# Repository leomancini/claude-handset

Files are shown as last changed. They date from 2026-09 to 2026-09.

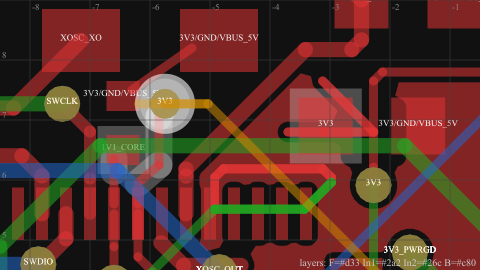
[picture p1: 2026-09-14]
patch-renders/caps_north_after_all.png

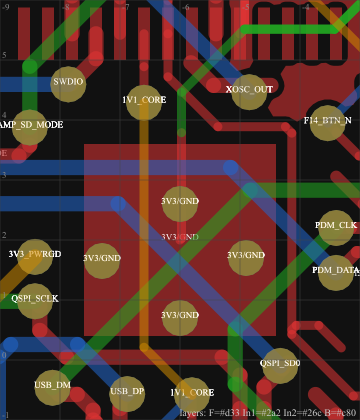
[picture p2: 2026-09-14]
patch-renders/site_ep.png

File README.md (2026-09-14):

# Claude Handset

60 mm round USB-C handset board: RP2040, MAX98357A speaker amp, Knowles PDM microphone, two
side buttons that send F13/F14 as a boot-compatible HID keyboard, all in one USB composite device.

Designed in [Flux](https://www.flux.ai/leomancini/claude-handset~2m). This repo holds the
hand-patched manufacturing files that were sent to JLCPCB (order 10211669A, September 2026),
the verification tooling, the enclosure STLs, and the ordering notes.

**Start with [CLAUDE.md](CLAUDE.md)** for the full hardware description, pin map, and firmware plan.

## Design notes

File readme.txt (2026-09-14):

Project Name: Claude Handset
Project Version: #3cf75256
Project Url: https://www.flux.ai/leomancini/claude-handset~2m

Project Description:
60 mm circular USB-C composite Audio + boot-compatible HID board with an onboard Knowles SPH0641LU4H-1 PDM MEMS microphone, MAX98357A amplified differential output for an 8 Ω speaker, and two separated diagonal side-actuated F13/F14 buttons.

Index:

Bottom Copper (Gerber): claude-handset-b_cu.gbr
Bottom Solder Mask (Gerber): claude-handset-b_mask.gbr
Bottom Solder Paste (Gerber): claude-handset-b_paste.gbr
Bottom Silkscreen (Gerber): claude-handset-b_silks.gbr
Board Outline (Gerber): claude-handset-edge_cuts.gbr
Top Copper (Gerber): claude-handset-f_cu.gbr
Top Solder Mask (Gerber): claude-handset-f_mask.gbr
Top Solder Paste (Gerber): claude-handset-f_paste.gbr
Top Silkscreen (Gerber): claude-handset-f_silks.gbr
Mid-Layer 1 (Gerber): claude-handset-in1_cu.gbr
Mid-Layer 2 (Gerber): claude-handset-in2_cu.gbr
Drill Holes (Excellon): claude-handset.drl
Electrical Test Netlist (IPC-D-356): claude-handset.d356
Component Positions, for assembly (Pick and Place, CSV): pick_and_place.csv

Bill of Materials: multiple versions are provided optimized for various contract manufacturers:

Bill of Materials (AdvancedCircuits): BOM/leomancini-claude-handset-BOM-V3cf75256-AdvancedCircuits.csv
Bill of Materials (AllPCB): BOM/leomancini-claude-handset-BOM-V3cf75256-AllPCB.csv
Bill of Materials (Elecrow): BOM/leomancini-claude-handset-BOM-V3cf75256-Elecrow.csv
Bill of Materials (Eurocircuits): BOM/leomancini-claude-handset-BOM-V3cf75256-Eurocircuits.csv
Bill of Materials (Flux): BOM/leomancini-claude-handset-BOM-V3cf75256-Flux.csv
Bill of Materials (JLCPCB): BOM/leomancini-claude-handset-BOM-V3cf75256-JLCPCB.csv
Bill of Materials (PCBWay): BOM/leomancini-claude-handset-BOM-V3cf75256-PCBWay.csv
Bill of Materials (Seeed): BOM/leomancini-claude-handset-BOM-V3cf75256-Seeed.csv

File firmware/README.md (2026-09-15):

# Claude Handset firmware

RP2040 firmware for the handset PCB. One USB full-speed composite device:

| Interface | What it is |
|---|---|
| UAC2 audio, speaker | 48 kHz, 16-bit stereo OUT, asynchronous with an explicit feedback endpoint. Mixed to mono, host volume + mute applied in firmware, played through the MAX98357A over I2S. The amp's SD_MODE pin is only high while the host is streaming and not muted. |
| UAC2 audio, microphone | 48 kHz, 16-bit mono IN. The Knowles PDM mic is clocked at 3.072 MHz by PIO and decimated in firmware (sinc⁴ ÷32 → DC blocker → half-band FIR ÷2). Host "input volume" is a digital gain, 0 to +30 dB, default +12 dB. |
| HID keyboard | Boot-protocol keyboard. SW1 sends **F17**, SW2 sends **F18** (see *Keys* below). 10 ms debounce, remote wakeup. |
| Reset | Raspberry Pi vendor "reset" interface so `picotool` can reboot the board into BOOTSEL without touching the buttons. |

macOS enumerates it as "Claude Handset" with 2 output and 1 input channel; the buttons show up as a keyboard.

## Build

Needs cmake, ninja, an `arm-none-eabi` GCC and the Pico SDK 2.3.1 (with its TinyUSB submodule). `build.sh` looks for the SDK in `~/.pico-sdk/sdk/2.3.1` and the toolchain in `~/.pico-sdk/toolchain/*/bin`, or set `PICO_SDK_PATH` / `PICO_TOOLCHAIN_PATH`.

```sh
brew install cmake ninja picotool
mkdir -p ~/.pico-sdk/sdk && git clone --depth 1 --branch 2.3.1 https://github.com/raspberrypi/pico-sdk ~/.pico-sdk/sdk/2.3.1
git -C ~/.pico-sdk/sdk/2.3.1 submodule update --init --depth 1 lib/tinyusb
# ARM toolchain: unpack arm-gnu-toolchain-*-darwin-arm64-arm-none-eabi.tar.xz into ~/.pico-sdk/toolchain/

./build.sh                        # -> build/claude_handset/claude_handset.uf2
./build.sh claude_handset_kb2040  # bench build for an Adafruit KB2040 wired to the same GPIOs
```

## Flash

```sh
./flash.sh          # picotool load -f --vid 0x1209 --pid 0x0001 -x build/claude_handset/claude_handset.uf2
```

Works in three states: blank flash (board boots straight into the ROM bootloader), a board put into BOOTSEL by hand (hold SW4, tap SW3, release SW4), or this firmware running (the reset interface reboots it). picotool only looks for the reset interface on Raspberry Pi's VID unless `--vid/--pid` are given, hence the flags.

## Recovery and crash diagnostics

The main loop feeds a 2 s watchdog. If it ever stalls:

1. First watchdog reboot: the board comes back normally but its USB serial number gets a suffix, `<uid>-WDT<stage>-<pc>-<loops>` (hex). `stage` is the last breadcrumb (`DIAG_CRUMB` in the sources; 10–15 = main-loop tasks, 20–24 speaker path, 3x set-interface, 4x control requests). Bit 0x8000 set = hard fault and `pc` is the faulting address; bit 0x4000 = `panic()` and `pc` is the address of the format string, `loops` the caller. Map addresses with `arm-none-eabi-addr2line -e build/claude_handset/claude_handset.elf`.
2. Second watchdog reboot in a row (within 10 s of boot): the board drops into the ROM bootloader and shows up as RPI-RP2, so it can always be reflashed.

Read the serial with `ioreg -p IOUSB -l -w0 | grep kUSBSerialNumberString`.

## Keys

The board was designed around F13/F14, but macOS binds F14/F15 to display brightness on keyboards without dedicated keys, so the firmware sends F17 and F18, which have no default binding on macOS, Windows or Linux. Change `HANDSET_KEY_SW1` / `HANDSET_KEY_SW2` in `src/buttons.c` to move them. `tools/keytest.html` is a browser page that lights up when the keys arrive.

## Live status

`tools/handset-status.c` reads a status block (stream state, amp pin, power-good, FIFO levels, frame counters, PIO/DMA positions) from the running board over the reset interface. Needs `brew install libusb`:

```sh
cc -O -o handset-status tools/handset-status.c -I/opt/homebrew/include -L/opt/homebrew/lib -lusb-1.0
./handset-status        # once
./handset-status 1      # every second
```

## Tunables

All in `src/usb_audio.c`:

- `SPK_HEADROOM_DB` (−6 dB): fixed attenuation on top of the host volume. The amp has 9 dB of gain and the board must stay under the 500 mA fuse, so a full-scale signal is never sent. Raise with a current meter in hand.
- `SPK_VOL_*_DB`, `MIC_VOL_*_DB`: ranges and defaults advertised to the host.
- `SPK_I2S_TARGET_FRAMES` (192 = 4 ms): how far ahead of the DMA reader the I2S ring is kept. Total speaker latency is this plus ~4 ms of USB FIFO.

`-DPDM_SAMPLE_ON_HIGH_PHASE=1` selects the alternate PDM sample edge (see `src/pdm_mic.pio`).

## Layout

```
boards/           board headers (claude_handset.h: pin map, 2 MB flash, QSPI /4)
src/main.c        init order + cooperative main loop
src/usb_descriptors.[ch]  device/config/string descriptors, UAC2 topology, HID report
src/usb_audio.[ch]        UAC2 requests, stream on/off, speaker + mic tasks, amp enable,
                          RP2040 ISO endpoint workaround
src/i2s_out.[ch] + .pio   I2S TX: PIO + two chained DMA channels on a 4 KB ring
src/pdm_mic.[ch] + .pio   PDM RX: PIO + DMA ring, CIC/half-band decimator
src/buttons.[ch]          debounce + HID keyboard reports
src/usb_reset.c           picotool reset interface + status request (TinyUSB app class driver)
src/handset_status.h      status block layout shared with tools/handset-status.c
src/diag.[ch]             watchdog policy, breadcrumbs, panic/hard-fault capture
src/tusb_config.h         TinyUSB configuration
tools/keytest.html        browser key tester
tools/handset-status.c    libusb tool that dumps the live status block
```

## Notes on things that bit

- **TinyUSB RP2040 ISO endpoints**: `usbd_edpt_close()` is a no-op on this port and re-activating an ISO endpoint does not clear its hardware buffer control. When the host stops a stream while a buffer is armed and later restarts it, the driver panics with "ep was already available". `rp2040_abort_endpoint()` in `usb_audio.c` aborts and clears the endpoints whenever a streaming interface goes to alt 0.
- **Feedback endpoint format**: on full speed the host expects a 3-byte 10.14 rate value. With TinyUSB's `CFG_TUD_AUDIO_ENABLE_FEEDBACK_FORMAT_CORRECTION` off it sends 4-byte 16.16, which macOS rejects: it delivers ~64 ms of audio, then stops sending packets for good while the interface stays at alt 1. Keep the correction on.
- **PDM sample point**: sample the data line on the clock edge that ends the mic's driving phase, with the PIO input synchroniser bypassed. Sampling near the other edge lands in the mic's output transition and shows up as noise.
- **DC blocker**: a first-order integer DC blocker leaves a residual of up to 255 counts unless the leak term keeps fractional bits; it is accumulated in Q8.
- **macOS makes a new USB audio device the default input and output.** Handy for testing, surprising for system sounds. `SwitchAudioSource` or the Sound settings put it back.

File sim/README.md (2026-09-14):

# Wiring simulator

Pure-Python (no dependencies) simulator that tests the board *as built from the copper*, not as
drawn in the schematic.

```
python3 sim/extract_netlist.py     # copper -> asbuilt_netlist.json  (about 2 min)
python3 sim/simulator.py           # DC simulation + wiring tests   -> results.md
```

## What it does

1. **extract_netlist.py** parses the four copper Gerbers and the drill file, unions every trace,
   pad, via and fill that physically touches (honouring negative-polarity clears), and drops every
   IPC-D-356 netlist point onto the resulting copper islands. Each island becomes one as-built net.
   Orphan pads, shorted nets and split nets are reported.

2. **simulator.py** builds a DC circuit on those as-built nets:
   - resistor values from `pick_and_place.csv`; fuse, ferrite, ESD-array pass-through and the
     8 Ω speaker as small resistances; switches open/closed per scenario;
   - behavioural MCP1825 LDO (3.3 V, dropout, open-drain PWRGD), RP2040 core regulator, GPIO
     drivers and internal pull-ups, and the supply currents of every IC;
   - RP2040 pin numbers are recovered from pad geometry and cross-checked against the netlist
     labels, so tests can refer to GPIO numbers.

   It then runs:
   - **netlist equivalence**: copper vs intended nets, GPIO assignments from the project description;
   - **two-terminal wiring paths**: 51 resistance measurements through the passive network
     (USB D+/D- through the ESD array and 27 Ω, CC pull-downs, QSPI to the flash, I2S and
     SD_MODE to the amp, PDM to the mic, SWD header, crystal, speaker, pull-ups, switches, and
     "must be open" pairs such as 3V3-GND and D+ to D-);
   - **decoupling placement**: net membership and distance of the nearest capacitor to every
     supply pin (warnings only);
   - **DC scenarios**: USB idle, each button, reset, BOOTSEL, debugger RUN, amp playing at 1 W,
     amp off, USB brown-out (PWRGD must go low), USB unplugged. Node voltages, fuse current and
     LDO dissipation are checked against expected windows.

Run against a different export with `GERBER_ROOT=<dir> NETLIST_OUT=<file>` for the extractor and
`NETLIST_IN=<file> RESULTS_OUT=<file>` for the simulator. `results_original.md` is the same
suite run on the untouched Flux export, where it flags the short and the opens.

## Limits

DC only: capacitors and the crystal are open circuits, so oscillator start-up, USB signal
integrity and audio are not simulated. Load currents and the SD_MODE pull-down are datasheet
estimates (listed at the end of `results.md`).

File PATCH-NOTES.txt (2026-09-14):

Claude Handset  #3cf75256  -  hand-patched Gerber export
=========================================================
These Gerbers were edited directly (the Flux project was NOT changed) to fix the
DRC faults Flux reported. Coordinates below are mm from the board centre, the same
origin as the IPC-D-356 netlist. Original files are byte-identical to the Flux
export except for the items listed here.

1. 3V3 shorted to 3V3_PWRGD (Flux "Overlapping Copper", Through-hole - 1)
   - Removed the 3V3 via at (-1.50, 4.00). It sat on the PWRGD trace and also
     overlapped the second 3V3 via 0.35 mm away.
   - Kept the 3V3 via at (-1.42, 3.66); its pad is now 0.5 mm (0.3 mm drill) on
     all four layers so it clears the PWRGD trace by 0.16 mm.
   - Deleted the three 0.1 mm top-layer feeder segments to the removed via and
     added a 0.15 mm segment from the existing 3V3 trace end (-1.83, 3.41) to the
     kept via.

2. 3V3 open (Flux "Airwire" 3V3, traces 7d11 / dcde)
   - The group feeding RP2040 VREG_VIN, USB_VDD, ADC_AVDD and three IOVDD pins
     (with C7, C8, C9, C13, C15, C16) was isolated.
   - Added a 3V3 via at (-12.79, -8.20) on the existing 3V3 trace just below
     FB1 pin 1, and a 0.254 mm inner-layer-1 trace from it to the existing 3V3
     via at (-9.16, -5.86). The ground planes on In1, In2 and Bottom are cleared
     0.2 mm around the new via and trace (negative-polarity LPC objects at the end
     of each copper file); the top ground fill is cleared around the via too.
   - Deleted the redundant top-layer 3V3 trace (-4.29,-4.00)-(-6.09,-4.00)-
     (-6.24,-1.47) between C10 and C14 (both ends are fed elsewhere) to make room
     for item 3.

3. GND opens (Flux "Airwire" GND, C10:P2 / C14:P2, traces 549b / ee7e, and the
   "Fill: None" items)
   - RP2040 exposed pad had no ground connection at all: added four 0.6 mm GND
     vias inside it at (-7.30, 1.65), (-4.90, 1.70), (-6.00, 2.60), (-6.00, 0.70).
   - C10:P2 and C14:P2: added a GND via at (-5.80, -4.10) with 0.25 mm links into
     both pads.
   - C13:P2 / C16:P2: added a 0.5 mm-pad GND via at (-8.50, -6.40) with a 0.3 mm
     link from the end of their wide stub at (-8.23, -6.06).

4. Drill file and IPC-D-356 netlist updated to match (7 vias added, 1 removed,
   one via pad size changed). Solder mask / paste files untouched: all vias in
   this export are tented, and no via was placed inside an SMD pad.

Verification (script-based, pure geometry from the Gerbers + netlist):
   - every net is one copper island; no island carries two nets; no floating copper
   - no new copper-to-copper spacing below 0.127 mm was introduced; the deleted
     0.1 mm feeders removed the worst pre-existing spacing (0.044 mm)
   - JLCPCB 4-layer limits used: 0.09 mm spacing, 0.15 mm via hole, 0.25 mm via pad

Not fixed (pre-existing, outside the DRC list): several spacings under 0.09 mm
remain from the original layout, e.g. USB-C pads vs traces at 0.050 mm around
(-0.25, -21.3), MCU_RUN pad vs SWDIO trace 0.069 mm at (-7.8, 5.4), F13/F14 button
traces vs 3V3 near the RP2040 east pins 0.069-0.089 mm.

Renders of the edited areas are in patch-renders/ (orig_* = before, site_* = after;
red = top, green = In1, blue = In2, orange = bottom).

Patch 2 - decoupling capacitors moved next to the pins they serve
================================================================
   - C24 (100 nF, VBUS_5V) moved from (7.0, -0.5) to (12.3, -4.6), directly below the
     MAX98357A VDD pins; its VBUS pad sits on the existing VDD trace, its GND pad on the
     top ground fill. Old pads and the two feeder segments removed. 1.18 mm from the pin.
   - C11 (100 nF, 1V1_CORE) moved from (-0.5, -3.0) to (-6.45, 6.95) and changed to an 0402
     (Samsung CL05B104KO5NNNC, LCSC C1525) so it fits between the RP2040's north pin row and
     the crystal. Its 1V1 pad is fed straight up from pin 23 (DVDD); its GND pad links to the
     crystal's GND pad. 1.07 mm from the pin. The BOMs and pick-and-place carry the new
     footprint. Old pads and five feeder stubs removed.
   - C6 (100 nF, 3V3) moved from (-1.5, 6.8) to (-2.3, 6.9), the closest an 0603 can get to
     RP2040 pin 22 (north IOVDD) without rerouting the crystal: 3.45 mm instead of 4.15 mm.
     Its 3V3 pad picks up the existing 3V3 stubs, its GND pad sits on the ground fill.
   - To make room for C11, pin 22's 3V3 feed now leaves the pad diagonally to x = -5.85 and
     the 3V3 via that fed it moved from (-6.19, 7.27) to (-5.75, 7.27) with a 0.5 mm pad;
     the bottom-layer 3V3 trace was redrawn to end on the moved via.
   - Top ground fill cleared 0.15 mm around every relocated non-GND pad and along the new
     top traces (negative-polarity objects at the end of f_cu); plane clearances added on
     the inner/bottom layers for the moved via. Mask and paste openings follow the pads;
     silkscreen body marks moved with the parts (the C24 label moved, the C6 and C11 labels
     were left where they were).
   - Re-verified: no shorts, no opens, no new spacing below 0.127 mm; wiring simulator
     142/143 with the remaining note being C6 at 3.45 mm.
   Renders: patch-renders/caps_north_*.png and caps_amp_*.png. Files before patch 2 are in
   the session scratchpad only; original-flux-export/ still holds the untouched export.

Gerber syntax note (after patch 2)
----------------------------------
   The patch blocks had deleted all file attributes (%TD*%) before the export's own trailing
   %TD.AperFunction*%, which a strict RS-274X parser rejects as deleting an undefined attribute.
   A %TA.AperFunction,Conductor*% line was added before that trailer in the four copper files.
   All 12 files now parse cleanly with an independent parser (gerbonara 1.x); the negative-
   polarity clearances render as intended there too. jlcpcb/ holds the upload pack.

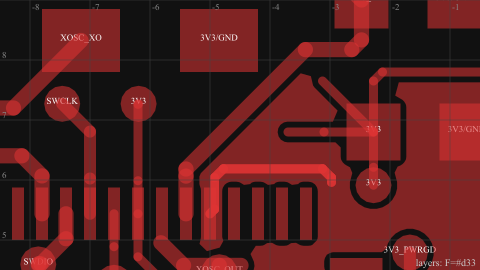
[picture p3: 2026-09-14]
patch-renders/caps_north_before.png

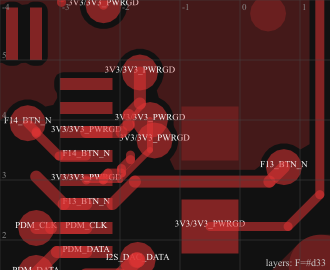
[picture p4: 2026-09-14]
patch-renders/orig_short_F.png

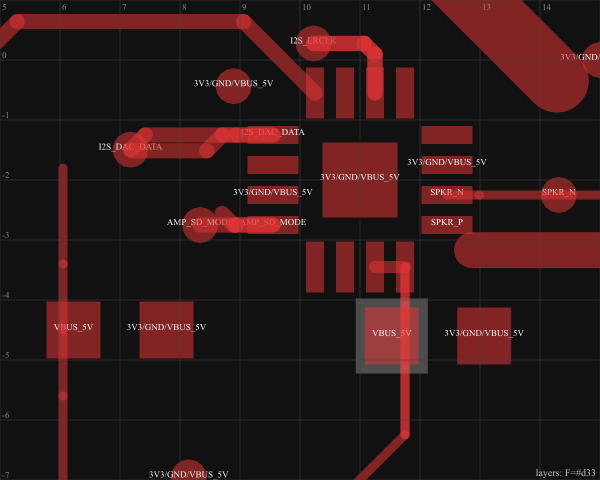
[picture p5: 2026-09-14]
patch-renders/caps_amp_after.png

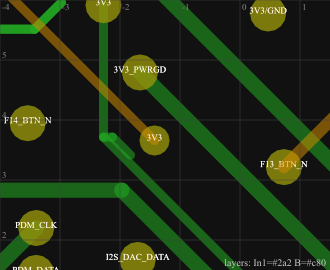
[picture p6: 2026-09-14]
patch-renders/site_short_In1B.png

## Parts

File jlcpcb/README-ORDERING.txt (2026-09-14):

Claude Handset  #3cf75256 (patched)  -  JLCPCB order pack
=========================================================

Files in this folder
--------------------
claude-handset-gerbers-v3cf75256-patched.zip   upload this in "Add gerber file"
                                              (11 Gerber layers + Excellon drill, RS-274X)
claude-handset-BOM-JLCPCB.csv                  BOM in JLCPCB's format (Comment, Designator, Footprint, LCSC Part #)
claude-handset-CPL-JLCPCB.csv                  component placement list (Designator, Mid X, Mid Y, Layer, Rotation)

PCB order settings (the quote form defaults are NOT right for this board)
------------------------------------------------------------------------
Base material ............ FR-4
Layers ................... 4          <- the form defaults to 2; this board has two inner planes
Dimensions ............... 60 x 60 mm (round board, the outline file sets the shape)
PCB thickness ............ 1.6 mm
Surface finish ........... ENIG recommended (0.4 mm pitch QFN-56 and USON-8 flash); HASL works for a prototype
Outer / inner copper ..... 1 oz / 0.5 oz
Via covering ............. Tented (all vias are tented in the export)
Min via hole / diameter .. 0.3 mm / 0.5 mm are the smallest used (JLC 4-layer min is 0.15 / 0.25)
Impedance control ........ No
Remove order number ...... "Specify a location" is not set up; choose "No" or "Yes" (JLC picks a spot)
Confirm production file .. Yes (recommended, see "things to check" below)

Assembly (if ordering SMT)
--------------------------
Side ...................... Top only (all 51 parts are on the top side)
Every part carries an LCSC number. JLCPCB's BOM matcher also finds U5 (MCP1825T-3302E/DC) as
C622691 even though the BOM cell is blank; if it ever shows unmatched, use C622691 or the
pin-compatible 1 A sibling MCP1826T-3302E/DC (C512184). Do NOT accept MCP1825S / MCP1825ST
(3-pin versions): they have no SHDN/PWRGD pins.
J1 (USB4105-GF-A, C3020560) is flagged "difficult to process" and JLCPCB leaves its row
UNSELECTED (qty 0) after the BOM upload. Click its magnifier, search C3020560, press Select;
it then shows qty 5 and adds a $0.03/pc special-component fee. In stock (1158 on 3 Sep 2026).
J3 (JST PH right-angle header) is through-hole: JLCPCB quotes it as hand-soldered, or leave it off
and solder it yourself. All other parts are SMD on the top side.
Rotation: JLCPCB re-orients parts to their library convention during review; check the pin-1
orientation of U1, U2, U3, U5, D1 in the assembly preview before confirming.

Things to check in JLCPCB's Gerber viewer / DFM before confirming
-----------------------------------------------------------------
1. This export was hand-patched (see ../PATCH-NOTES.txt). Copper clearances around the new
   parts use negative-polarity Gerber objects (%LPC). Both my own checker and an independent
   parser (gerbonara) read them correctly; still, look at these four spots in the viewer and
   make sure the 3V3 pads/vias are NOT merged into the ground fill:
     - the via just below FB1 at board-centre coords (-12.8, -8.2)
     - the RP2040's north side, (-7 .. -2, 6 .. 8): C6, C11 and the moved 3V3 via
     - below the amp U3 at (11.5, -4.6): C24
     - the 3V3 via at (-1.4, 3.7) next to the RP2040's east pins
2. The original Flux layout has several spacings below JLCPCB's 0.09 mm minimum that were not
   touched: USB-C pads vs traces at 0.05 mm around (-0.3, -21.3), RUN pad vs SWDIO trace 0.07 mm
   at (-7.8, 5.4), F13/F14 traces vs 3V3 near the RP2040 east pins at 0.07-0.09 mm. Expect an
   engineering query; accept their "adjust spacing" fix if offered.
3. Silkscreen: the labels "C6" and "C11" still sit at the parts' old positions (cosmetic).

Cart as saved on 3 September 2026 (order 10211669A, not paid)
--------------------------------------------------------------
PCB   : 4 layers, 1.6 mm, ENIG, plugged vias, Confirm Production File = Yes ........ $28.38
PCBA  : Standard, top side, 5 pcs, 26 parts, Confirm Parts Placement = Yes ......... $154.40
U3 (MAX98357A) was rotated right 90 deg in the placement viewer so its pin-1 dot sits on the
footprint's pin-1 mark (top-left). All other parts were accepted as auto-aligned.
Note: the cart lists the PCB dimension as 70 x 70 mm. The outline is a 60 mm circle whose
Gerber coordinates span 10..70 mm, and JLCPCB measured from the origin. Production follows
the outline file; the size only affects price. Correct it to 60 x 60 in "Edit Order" if you
want the exact quote (last time Edit Order removed the item and re-saving failed, so only
do it if you are prepared to rebuild the cart).

Engineer query 4 September 2026 (order 10211669A): C25 pads too small for the part
------------------------------------------------------------------------------------
Correct. Flux's BOM put C25 on the 0805 line (C15850) but the copper footprint is 0603
(same pads as C1). Answer: option A, replace C25 with C96446 (CL10A106MA8NRNC, 10uF 25V
X5R 0603), the same part as C1. The BOM and CPL in this folder are now corrected, so a
future upload will not repeat it. All other passives were checked against their pads: OK.
Resolution 5 September 2026: JLCPCB's Replace Parts page groups C2, C25, C3 on one line, so
the whole line was switched to C96446 (0603) for this order. C2 and C3 sit on 0805 pads with
the smaller body; electrically identical. The BOM here keeps C2/C3 on C15850 (0805) and C25
on C96446 (0603), which is the correct split for any future order.

Production-file check 5 September 2026 (JLCPCB pack ~/Downloads/claude-handset-gerbers-v3cf75256-patched_Y8)
-----------------------------------------------------------------------------------------------------------
Their CAM output (ok/tl, l2, l3, bl, ts, bs, to, drl, ko) was compared against the uploaded files
(shift is exactly -5 mm, +75 mm; YG/ zip is byte-identical to the upload).
  copper top/bottom ... identical inside the board outline
  copper inner ........ identical except non-functional via/through-hole pads removed (standard CAM step)
  copper at edges ..... pulled back ~0.3 mm from the board edge and from the NPTH mic hole (standard)
  solder mask ......... identical, plus mask opened over the USB-C NPTH slots and the mic hole
  silkscreen .......... identical, clipped where it crossed pads
  drill ............... all 114 holes and 4 USB-C slots present; 4 extra tooling holes in the rails
  connectivity ........ netlist replayed on THEIR copper: 319 pads, 0 opens, 0 shorts
  panel ............... 70 x 70 mm frame: 5 mm rails left/right, 3 mm top/bottom, QR code + tooling
                        holes on the rails, via plugging list (sk). This is why the order says 70 x 70.
                        Boards ship in the frame (depanel = No); snap them out. Expect small flats/rough
                        spots at the 3 and 9 o'clock edges where the tabs were.
Verdict: OK to confirm.

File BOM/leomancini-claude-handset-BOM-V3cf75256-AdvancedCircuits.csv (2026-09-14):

Component Description | QTY | Ref Des | Mfg P/N # | Manufacturer | Distributor P/N #
Non-Polarized Capacitor, 10uF, SMD_0603_1608Metric | 1 | C1 | CL10A106MA8NRNC | Samsung Electro-Mechanics | C96446
Non-Polarized Capacitor, 10uF, SMD_0805_2012Metric | 3 | C2,C25,C3 | CL21A106KAYNNNE | Samsung Electro-Mechanics | C15850
Non-Polarized Capacitor, 100nF, SMD_0603_1608Metric | 13 | C10,C15,C16,C17,C20,C24,C28,C4,C5,C6,C7,C8,C9 | CL10B104KB8NNNC | Samsung Electro-Mechanics | C1591
Non-Polarized Capacitor, 100nF, SMD_0402_1005Metric | 1 | C11 | CL05B104KO5NNNC | Samsung Electro-Mechanics | C1525
Non-Polarized Capacitor, 27pF, SMD_0603_1608Metric | 2 | C12,C18 | CL10C270JB8NNNC | Samsung Electro-Mechanics | C1656
Non-Polarized Capacitor, 1uF, SMD_0603_1608Metric | 2 | C13,C14 | CL10A105KB8NNNC | Samsung Electro-Mechanics | C15849
Non-Polarized Capacitor, 47pF, SMD_0603_1608Metric | 1 | C29 | CL10C470JB8NNNC | Samsung Electro-Mechanics | C1671
Protection | 1 | D1 | USBLC6-2SC6 | STMicroelectronics
TVS, SOD-123FL_L2.8-W1.8-LS3.6-RD | 1 | D2 | SMF5.0A | Liown(里阳半导体)
Circuit Protection Devices | 1 | F1 | SMD050F-2 | Littelfuse | C428837
Ferrite Bead | 1 | FB1 | BLM18AG601SN1D | Murata Electronics | C19330
USB C | 1 | J1 | USB4105-GF-A | GCT | C3020560
Wire To Board / Wire To Wire Connector, CONN-TH_S2B-PH-K-S-LF-SN | 1 | J3 | S2B-PH-K-S(LF)(SN) | JST
Connector | 1 | J4 | FTSH-103-01-L-DV | Samtec | C3324375
Microphone | 1 | MK1 | SPH0641LU4H-1 | Knowles | C2879853
Resistor, 5.1kΩ, SMD_0603_1608Metric | 2 | R1,R2 | 0603WAF5101T5E | UNI-ROYAL | C23186
Resistor, 27Ω, SMD_0603_1608Metric | 2 | R3,R4 | 0603WAF270JT5E | UNI-ROYAL | C25190
Resistor, 1kΩ, SMD_0603_1608Metric | 2 | R5,R6 | 0603WAF1001T5E | UNI-ROYAL | C21190
Resistor, 10kΩ, SMD_0603_1608Metric | 5 | R14,R15,R7,R8,R9 | 0603WAF1002T5E | UNI-ROYAL | C25804
Switch | 2 | SW1,SW2 | B3U-3000P | Omron Electronics Inc-EMC Div | C963349
Tactile Switches, SW-SMD_L3.9-W3.0-P4.45 | 2 | SW3,SW4 | TS-1088-AR02016 | XUNPU(讯普)
, QFN-56-1EP_7x7mm_P0.4mm_EP3.2x3.2mm | 1 | U1 | RP2040 | Arm Ltd. | C2040
NOR FLASH, USON-8_L3.0-W2.0-P0.50-BL-EP | 1 | U2 | W25Q16JVUXIQ | WINBOND(华邦)
 | 1 | U3 | MAX98357AETE+T | Maxim Integrated Products, Inc. | C910544
Linear Regulator, SOT-223 | 1 | U5 | MCP1825T-3302E/DC | Microchip Technology
Crystals and Oscillators | 1 | Y1 | ABM8-272-T3 | Abracon | C20625731

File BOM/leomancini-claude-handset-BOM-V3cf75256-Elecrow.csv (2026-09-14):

*Reference | *Manufacturer Part number | *QTY | *Original | Description | Purchase Link
"C1" | "CL10A106MA8NRNC" | "1" | "" | "A generic fixed capacitor ideal for rapid circuit topology development. You can choose between polarized and non-polarized types | its symbol and the footprint will automatically adapt based on your selection. Supported options include standard SMD sizes for ceramic capacitors (e.g. | 0402 | 0603 | 0805) | SMD sizes for aluminum electrolytic capacitors | and through-hole footprints for polarized capacitors.
Save precious design time by seamlessly add more information to this part (value | footprint | etc.) as it becomes available.
Standard capacitor values: 1.0pF | 10pF | 100pF | 1000pF | 0.01uF | 0.1uF | 1.0uF | 10uF | 100uF | 1000uF | 10000uF
1.1pF | 11pF | 110pF | 1100pF
1.2pF | 12pF | 120pF | 1200pF
1.3pF | 13pF | 130pF | 1300pF
1.5pF | 15pF | 150pF | 1500pF | 0.015uF | 0.15uF | 1.5uF | 15uF | 150uF | 1500uF
1.6pF | 16pF | 160pF | 1600pF
1.8pF | 18pF | 180pF | 1800pF
2.0pF | 20pF | 200pF | 2000pF
2.2pF | 22pF | 220pF | 2200pF | 0.022uF | 0.22uF | 2.2uF | 22uF | 220uF | 2200uF
2.4pF | 24pF | 240pF | 2400pF
2.7pF | 27pF | 270pF | 2700pF
3.0pF | 30pF | 300pF | 3000pF
3.3pF | 33pF | 330pF | 3300pF | 0.033uF | 0.33uF | 3.3uF | 33uF | 330uF | 3300uF
3.6pF | 36pF | 360pF | 3600pF
3.9pF | 39pF | 390pF | 3900pF
4.3pF | 43pF | 430pF | 4300pF
4.7pF | 47pF | 470pF | 4700pF | 0.047uF | 0.47uF | 4.7uF | 47uF | 470uF | 4700uF
5.1pF | 51pF | 510pF | 5100pF
5.6pF | 56pF | 560pF | 5600pF
6.2pF | 62pF | 620pF | 6200pF
6.8pF | 68pF | 680pF | 6800pF | 0.068uF | 0.68uF | 6.8uF | 68uF | 680uF | 6800uF
7.5pF | 75pF | 750pF | 7500pF
8.2pF | 82pF | 820pF | 8200pF
9.1pF | 91pF | 910pF | 9100pF #generics #CommonPartsLibrary" | ""
"C2 | C25 | C3" | "CL21A106KAYNNNE" | "3" | "" | "A generic fixed capacitor ideal for rapid circuit topology development. You can choose between polarized and non-polarized types | its symbol and the footprint will automatically adapt based on your selection. Supported options include standard SMD sizes for ceramic capacitors (e.g. | 0402 | 0603 | 0805) | SMD sizes for aluminum electrolytic capacitors | and through-hole footprints for polarized capacitors.
Save precious design time by seamlessly add more information to this part (value | footprint | etc.) as it becomes available.
Standard capacitor values: 1.0pF | 10pF | 100pF | 1000pF | 0.01uF | 0.1uF | 1.0uF | 10uF | 100uF | 1000uF | 10000uF
1.1pF | 11pF | 110pF | 1100pF
1.2pF | 12pF | 120pF | 1200pF
1.3pF | 13pF | 130pF | 1300pF
1.5pF | 15pF | 150pF | 1500pF | 0.015uF | 0.15uF | 1.5uF | 15uF | 150uF | 1500uF
1.6pF | 16pF | 160pF | 1600pF
1.8pF | 18pF | 180pF | 1800pF
2.0pF | 20pF | 200pF | 2000pF
2.2pF | 22pF | 220pF | 2200pF | 0.022uF | 0.22uF | 2.2uF | 22uF | 220uF | 2200uF
2.4pF | 24pF | 240pF | 2400pF
2.7pF | 27pF | 270pF | 2700pF
3.0pF | 30pF | 300pF | 3000pF
3.3pF | 33pF | 330pF | 3300pF | 0.033uF | 0.33uF | 3.3uF | 33uF | 330uF | 3300uF
3.6pF | 36pF | 360pF | 3600pF
3.9pF | 39pF | 390pF | 3900pF
4.3pF | 43pF | 430pF | 4300pF
4.7pF | 47pF | 470pF | 4700pF | 0.047uF | 0.47uF | 4.7uF | 47uF | 470uF | 4700uF
5.1pF | 51pF | 510pF | 5100pF
5.6pF | 56pF | 560pF | 5600pF
6.2pF | 62pF | 620pF | 6200pF
6.8pF | 68pF | 680pF | 6800pF | 0.068uF | 0.68uF | 6.8uF | 68uF | 680uF | 6800uF
7.5pF | 75pF | 750pF | 7500pF
8.2pF | 82pF | 820pF | 8200pF
9.1pF | 91pF | 910pF | 9100pF #generics #CommonPartsLibrary" | ""
"C10 | C15 | C16 | C17 | C20 | C24 | C28 | C4 | C5 | C6 | C7 | C8 | C9" | "CL10B104KB8NNNC" | "13" | "" | "A generic fixed capacitor ideal for rapid circuit topology development. You can choose between polarized and non-polarized types | its symbol and the footprint will automatically adapt based on your selection. Supported options include standard SMD sizes for ceramic capacitors (e.g. | 0402 | 0603 | 0805) | SMD sizes for aluminum electrolytic capacitors | and through-hole footprints for polarized capacitors.
Save precious design time by seamlessly add more information to this part (value | footprint | etc.) as it becomes available.
Standard capacitor values: 1.0pF | 10pF | 100pF | 1000pF | 0.01uF | 0.1uF | 1.0uF | 10uF | 100uF | 1000uF | 10000uF
1.1pF | 11pF | 110pF | 1100pF
1.2pF | 12pF | 120pF | 1200pF
1.3pF | 13pF | 130pF | 1300pF
1.5pF | 15pF | 150pF | 1500pF | 0.015uF | 0.15uF | 1.5uF | 15uF | 150uF | 1500uF
1.6pF | 16pF | 160pF | 1600pF
1.8pF | 18pF | 180pF | 1800pF
2.0pF | 20pF | 200pF | 2000pF
2.2pF | 22pF | 220pF | 2200pF | 0.022uF | 0.22uF | 2.2uF | 22uF | 220uF | 2200uF
2.4pF | 24pF | 240pF | 2400pF
2.7pF | 27pF | 270pF | 2700pF
3.0pF | 30pF | 300pF | 3000pF
3.3pF | 33pF | 330pF | 3300pF | 0.033uF | 0.33uF | 3.3uF | 33uF | 330uF | 3300uF
3.6pF | 36pF | 360pF | 3600pF
3.9pF | 39pF | 390pF | 3900pF
4.3pF | 43pF | 430pF | 4300pF
4.7pF | 47pF | 470pF | 4700pF | 0.047uF | 0.47uF | 4.7uF | 47uF | 470uF | 4700uF
5.1pF | 51pF | 510pF | 5100pF
5.6pF | 56pF | 560pF | 5600pF
6.2pF | 62pF | 620pF | 6200pF
6.8pF | 68pF | 680pF | 6800pF | 0.068uF | 0.68uF | 6.8uF | 68uF | 680uF | 6800uF
7.5pF | 75pF | 750pF | 7500pF
8.2pF | 82pF | 820pF | 8200pF
9.1pF | 91pF | 910pF | 9100pF #generics #CommonPartsLibrary" | ""
"C11" | "CL05B104KO5NNNC" | "1" | "" | "A generic fixed capacitor ideal for rapid circuit topology development. You can choose between polarized and non-polarized types | its symbol and the footprint will automatically adapt based on your selection. Supported options include standard SMD sizes for ceramic capacitors (e.g. | 0402 | 0603 | 0805) | SMD sizes for aluminum electrolytic capacitors | and through-hole footprints for polarized capacitors.
Save precious design time by seamlessly add more information to this part (value | footprint | etc.) as it becomes available.
Standard capacitor values: 1.0pF | 10pF | 100pF | 1000pF | 0.01uF | 0.1uF | 1.0uF | 10uF | 100uF | 1000uF | 10000uF
1.1pF | 11pF | 110pF | 1100pF
1.2pF | 12pF | 120pF | 1200pF
1.3pF | 13pF | 130pF | 1300pF
1.5pF | 15pF | 150pF | 1500pF | 0.015uF | 0.15uF | 1.5uF | 15uF | 150uF | 1500uF
1.6pF | 16pF | 160pF | 1600pF
1.8pF | 18pF | 180pF | 1800pF
2.0pF | 20pF | 200pF | 2000pF
2.2pF | 22pF | 220pF | 2200pF | 0.022uF | 0.22uF | 2.2uF | 22uF | 220uF | 2200uF
2.4pF | 24pF | 240pF | 2400pF
2.7pF | 27pF | 270pF | 2700pF
3.0pF | 30pF | 300pF | 3000pF
3.3pF | 33pF | 330pF | 3300pF | 0.033uF | 0.33uF | 3.3uF | 33uF | 330uF | 3300uF
3.6pF | 36pF | 360pF | 3600pF
3.9pF | 39pF | 390pF | 3900pF
4.3pF | 43pF | 430pF | 4300pF
4.7pF | 47pF | 470pF | 4700pF | 0.047uF | 0.47uF | 4.7uF | 47uF | 470uF | 4700uF
5.1pF | 51pF | 510pF | 5100pF
5.6pF | 56pF | 560pF | 5600pF
6.2pF | 62pF | 620pF | 6200pF
6.8pF | 68pF | 680pF | 6800pF | 0.068uF | 0.68uF | 6.8uF | 68uF | 680uF | 6800uF
7.5pF | 75pF | 750pF | 7500pF
8.2pF | 82pF | 820pF | 8200pF
9.1pF | 91pF | 910pF | 9100pF #generics #CommonPartsLibrary" | ""
"C12 | C18" | "CL10C270JB8NNNC" | "2" | "" | "A generic fixed capacitor ideal for rapid circuit topology development. You can choose between polarized and non-polarized types | its symbol and the footprint will automatically adapt based on your selection. Supported options include standard SMD sizes for ceramic capacitors (e.g. | 0402 | 0603 | 0805) | SMD sizes for aluminum electrolytic capacitors | and through-hole footprints for polarized capacitors.
Save precious design time by seamlessly add more information to this part (value | footprint | etc.) as it becomes available.
Standard capacitor values: 1.0pF | 10pF | 100pF | 1000pF | 0.01uF | 0.1uF | 1.0uF | 10uF | 100uF | 1000uF | 10000uF
1.1pF | 11pF | 110pF | 1100pF
1.2pF | 12pF | 120pF | 1200pF
1.3pF | 13pF | 130pF | 1300pF
1.5pF | 15pF | 150pF | 1500pF | 0.015uF | 0.15uF | 1.5uF | 15uF | 150uF | 1500uF
1.6pF | 16pF | 160pF | 1600pF
1.8pF | 18pF | 180pF | 1800pF
2.0pF | 20pF | 200pF | 2000pF
2.2pF | 22pF | 220pF | 2200pF | 0.022uF | 0.22uF | 2.2uF | 22uF | 220uF | 2200uF
2.4pF | 24pF | 240pF | 2400pF
2.7pF | 27pF | 270pF | 2700pF
3.0pF | 30pF | 300pF | 3000pF
3.3pF | 33pF | 330pF | 3300pF | 0.033uF | 0.33uF | 3.3uF | 33uF | 330uF | 3300uF
3.6pF | 36pF | 360pF | 3600pF
3.9pF | 39pF | 390pF | 3900pF
4.3pF | 43pF | 430pF | 4300pF
4.7pF | 47pF | 470pF | 4700pF | 0.047uF | 0.47uF | 4.7uF | 47uF | 470uF | 4700uF
5.1pF | 51pF | 510pF | 5100pF
5.6pF | 56pF | 560pF | 5600pF
6.2pF | 62pF | 620pF | 6200pF
6.8pF | 68pF | 680pF | 6800pF | 0.068uF | 0.68uF | 6.8uF | 68uF | 680uF | 6800uF
7.5pF | 75pF | 750pF | 7500pF
8.2pF | 82pF | 820pF | 8200pF
9.1pF | 91pF | 910pF | 9100pF #generics #CommonPartsLibrary" | ""
"C13 | C14" | "CL10A105KB8NNNC" | "2" | "" | "A generic fixed capacitor ideal for rapid circuit topology development. You can choose between polarized and non-polarized types | its symbol and the footprint will automatically adapt based on your selection. Supported options include standard SMD sizes for ceramic capacitors (e.g. | 0402 | 0603 | 0805) | SMD sizes for aluminum electrolytic capacitors | and through-hole footprints for polarized capacitors.
Save precious design time by seamlessly add more information to this part (value | footprint | etc.) as it becomes available.
Standard capacitor values: 1.0pF | 10pF | 100pF | 1000pF | 0.01uF | 0.1uF | 1.0uF | 10uF | 100uF | 1000uF | 10000uF
1.1pF | 11pF | 110pF | 1100pF
1.2pF | 12pF | 120pF | 1200pF
1.3pF | 13pF | 130pF | 1300pF
1.5pF | 15pF | 150pF | 1500pF | 0.015uF | 0.15uF | 1.5uF | 15uF | 150uF | 1500uF
1.6pF | 16pF | 160pF | 1600pF
1.8pF | 18pF | 180pF | 1800pF
2.0pF | 20pF | 200pF | 2000pF
2.2pF | 22pF | 220pF | 2200pF | 0.022uF | 0.22uF | 2.2uF | 22uF | 220uF | 2200uF
2.4pF | 24pF | 240pF | 2400pF
2.7pF | 27pF | 270pF | 2700pF
3.0pF | 30pF | 300pF | 3000pF
3.3pF | 33pF | 330pF | 3300pF | 0.033uF | 0.33uF | 3.3uF | 33uF | 330uF | 3300uF
3.6pF | 36pF | 360pF | 3600pF
3.9pF | 39pF | 390pF | 3900pF
4.3pF | 43pF | 430pF | 4300pF
4.7pF | 47pF | 470pF | 4700pF | 0.047uF | 0.47uF | 4.7uF | 47uF | 470uF | 4700uF
5.1pF | 51pF | 510pF | 5100pF
5.6pF | 56pF | 560pF | 5600pF
6.2pF | 62pF | 620pF | 6200pF
6.8pF | 68pF | 680pF | 6800pF | 0.068uF | 0.68uF | 6.8uF | 68uF | 680uF | 6800uF
7.5pF | 75pF | 750pF | 7500pF
8.2pF | 82pF | 820pF | 8200pF
9.1pF | 91pF | 910pF | 9100pF #generics #CommonPartsLibrary" | ""
"C29" | "CL10C470JB8NNNC" | "1" | "" | "A generic fixed capacitor ideal for rapid circuit topology development. You can choose between polarized and non-polarized types | its symbol and the footprint will automatically adapt based on your selection. Supported options include standard SMD sizes for ceramic capacitors (e.g. | 0402 | 0603 | 0805) | SMD sizes for aluminum electrolytic capacitors | and through-hole footprints for polarized capacitors.
Save precious design time by seamlessly add more information to this part (value | footprint | etc.) as it becomes available.
Standard capacitor values: 1.0pF | 10pF | 100pF | 1000pF | 0.01uF | 0.1uF | 1.0uF | 10uF | 100uF | 1000uF | 10000uF
1.1pF | 11pF | 110pF | 1100pF
1.2pF | 12pF | 120pF | 1200pF
1.3pF | 13pF | 130pF | 1300pF
1.5pF | 15pF | 150pF | 1500pF | 0.015uF | 0.15uF | 1.5uF | 15uF | 150uF | 1500uF
1.6pF | 16pF | 160pF | 1600pF
1.8pF | 18pF | 180pF | 1800pF
2.0pF | 20pF | 200pF | 2000pF
2.2pF | 22pF | 220pF | 2200pF | 0.022uF | 0.22uF | 2.2uF | 22uF | 220uF | 2200uF
2.4pF | 24pF | 240pF | 2400pF
2.7pF | 27pF | 270pF | 2700pF
3.0pF | 30pF | 300pF | 3000pF
3.3pF | 33pF | 330pF | 3300pF | 0.033uF | 0.33uF | 3.3uF | 33uF | 330uF | 3300uF
3.6pF | 36pF | 360pF | 3600pF
3.9pF | 39pF | 390pF | 3900pF
4.3pF | 43pF | 430pF | 4300pF
4.7pF | 47pF | 470pF | 4700pF | 0.047uF | 0.47uF | 4.7uF | 47uF | 470uF | 4700uF
5.1pF | 51pF | 510pF | 5100pF
5.6pF | 56pF | 560pF | 5600pF
6.2pF | 62pF | 620pF | 6200pF
6.8pF | 68pF | 680pF | 6800pF | 0.068uF | 0.68uF | 6.8uF | 68uF | 680uF | 6800uF
7.5pF | 75pF | 750pF | 7500pF
8.2pF | 82pF | 820pF | 8200pF
9.1pF | 91pF | 910pF | 9100pF #generics #CommonPartsLibrary" | ""
"D1" | "USBLC6-2SC6" | "1" | "" | "17V Clamp 5A (8/20µs) Ipp Tvs Diode Surface Mount SOT-23-6 #C7519" | ""
"D2" | "SMF5.0A" | "1" | "" | "9.2VC Clamp 21.8A Ipp TVS DIODE SOD-123FL
The SMF5.0A is a unidirectional Transient Voltage Suppressor (TVS) diode designed to protect sensitive electronic circuits from electrostatic discharge (ESD) | lightning surges | and other transient overvoltage events. It is commonly used on 5V power rails | USB VBUS lines | DC inputs | and general-purpose power protection applications. The device comes in a compact surface-mount SOD-123FL/SMF package suitable for space-constrained PCB designs.
Key Features
5V reverse standoff voltage (VRWM)
200W peak pulse power dissipation (10/1000µs waveform)
Fast response time for transient suppression
Low clamping voltage (~9.2V max)
Unidirectional TVS protection
Excellent ESD and surge protection capability
Compact SOD-123FL / SMF surface-mount package
Low leakage current
Operating temperature up to +150°C
RoHS compliant and halogen-free variants available" | ""
"F1" | "SMD050F-2" | "1" | "" | "Polymeric PTC Resettable Fuse 60V 500 mA Ih Surface Mount 2-SMD 500mA resettable fuse pptc
The SMD050F-2 is a surface-mount resettable fuse (PPTC – Polymer Positive Temperature Coefficient) designed to provide overcurrent protection in low-voltage electronic circuits. It operates by increasing its resistance significantly when excessive current flows | thereby limiting current and protecting downstream components. Once the fault condition is removed and the device cools | it automatically resets to its low-resistance state | enabling normal operation without replacement.
This component is commonly used in power supply lines | USB ports | battery-powered devices | and general electronic protection applications where space-saving and reliability are important.
Key Features
Resettable overcurrent protection (self-recovering)
Surface-mount package for compact PCB layouts
Low resistance in normal operation
Fast response to fault conditions
Automatic reset after fault removal
RoHS compliant and lead-free
Electrical Characteristics
Hold current: 0.5 A
Trip current: 1.0 A (typical)
Maximum voltage: 60 V
Maximum current: 40 A (fault current rating)
Initial resistance: low resistance range suitable for minimal voltage drop
Resistance after trip: significantly increased to limit current
Thermal Characteristics
Operating temperature range: -40°C to +85°C
Trip time dependent on applied current and ambient temperature
Reset time dependent on cooling conditions
Mechanical Characteristics
Package type: Surface-mount (SMD)
Compact footprint suitable for dense PCB layouts
Compatible with standard reflow soldering processes
Applications
USB and peripheral port protection
Power supply and DC line protection
Battery pack protection
Consumer electronics
Industrial control circuits
Compliance and Standards
RoHS compliant
Halogen-free (depending on manufacturer variant)
Meets industry standards for resettable fuses
#commonpartslibrary
#circuitprotection
#ptc
#fuse" | ""
"FB1" | "BLM18AG601SN1D" | "1" | "" | "600 Ohms @ 100 MHz 1 Ferrite Bead 0603 (1608 Metric) ferrite bead 600 ohm 0603 ferrite bead 600 ohm 100MHz 0603 ferrite bead 0603 600ohm
The BLM18AG601SN1D is a surface-mount ferrite bead designed for suppression of high-frequency noise in electronic circuits. It provides high impedance at high frequencies while maintaining low DC resistance | making it suitable for power lines and signal line filtering. This component is commonly used in portable electronics | communication devices | and general digital circuits to improve EMI performance.
ELECTRICAL CHARACTERISTICS
Impedance: 600 Ω ±25% @ 100 MHz
Rated Current: 500 mA (max)
DC Resistance (DCR): 0.5 Ω (typ) | 0.8 Ω (max)
Insulation Resistance: 10 MΩ min
PHYSICAL CHARACTERISTICS
Package Size: 0603 (1608 Metric)
Length: 1.6 mm
Width: 0.8 mm
Height: 0.8 mm (typ)
Mounting Type: Surface Mount (SMD)
ENVIRONMENTAL & OPERATING CONDITIONS
Operating Temperature Range: -55°C to +125°C
Storage Temperature Range: -55°C to +125°C
APPLICATIONS
Power supply line noise suppression
Signal line EMI filtering
Mobile devices and handheld electronics
Computers and peripherals
Consumer electronics
FEATURES
High impedance at high frequencies for effective noise suppression
Low DC resistance minimizes signal/power loss
Compact 0603 package suitable for high-density PCB layouts
Reliable multilayer construction
Lead-free and RoHS compliant
PACKAGING
Packaging Type: Tape and Reel
Standard Reel Quantity: Typically 4000 pcs/reel
#CommonPartLibrary #Filter #FerriteBead" | ""
"J1" | "USB4105-GF-A" | "1" | "" | "USB Type-C receptacle connector providing a USB 2.0 interface for PCB top-mount applications. This surface-mount receptacle is rated for 48 VDC and 240 W | with a 5.0 A collective VBUS current rating | 6.25 A collective GND current rating | 1.25 A VCONN current rating | and an operating temperature range of -40°C to +85°C.
#USBTypeC #USB2_0 #ReceptacleConnector #SMT #TopMount #48V #240W #5A #GCT #PCBComponents" | ""
"J3" | "S2B-PH-K-S(LF)(SN)" | "1" | "" | "Wire To Board / Wire To Wire Connector
S2B-PH-K-S(LF)(SN)
CONN-TH_S2B-PH-K-S-LF-SN
LCSC Part Number: C173752
JLCPCB Part Class: Extended Part
Manufactured by JST
Connector Header Through Hole | Right Angle 2 position
battery connector JST PH 2-pin" | ""
"J4" | "FTSH-103-01-L-DV" | "1" | "" | " Connector Header Surface Mount 6 position 0.050"" (1.27mm)
2x3 header 1.27mm
2x3 SWD debug header
pin header 2x3 1.27mm
2x3 1.27mm pin header" | ""
"MK1" | "SPH0641LU4H-1" | "1" | "" | "100 Hz ~ 80 kHz Digital | PDM Microphone MEMS (Silicon) 1.62 V ~ 3.6 V Omnidirectional (-26dB ±1dB @ 94dB SPL) Solder Pads #CommonPartsLibrary #Audio #MEMS #Microphone" | ""
"R1 | R2" | "0603WAF5101T5E" | "2" | "" | "A generic fixed resistor ideal for rapid circuit topology development. Its footprint automatically adapts based on the selected package case code—supporting 0402 | 0603 | 0805 | 1203 | and many other standard SMD packages | as well as axial horizontal and vertical configurations.
Save precious design time by seamlessly add more information to this part (value | footprint | etc.) as it becomes available.
Standard resistor values:
1.0 ohm | 10 ohm | 100 ohm | 1.0k ohm | 10k ohm | 100k ohm | 1.0M ohm
1.1 ohm | 11 ohm | 110 ohm | 1.1k ohm | 11k ohm | 110k ohm | 1.1M ohm
1.2 ohm | 12 ohm | 120 ohm | 1.2k ohm | 12k ohm | 120k ohm | 1.2M ohm
1.3 ohm | 13 ohm | 130 ohm | 1.3k ohm | 13k ohm | 130k ohm | 1.3M ohm
1.5 ohm | 15 ohm | 150 ohm | 1.5k ohm | 15k ohm | 150k ohm | 1.5M ohm
1.6 ohm | 16 ohm | 160 ohm | 1.6k ohm | 16k ohm | 160k ohm | 1.6M ohm
1.8 ohm | 18 ohm | 180 ohm | 1.8K ohm | 18k ohm | 180k ohm | 1.8M ohm
2.0 ohm | 20 ohm | 200 ohm | 2.0k ohm | 20k ohm | 200k ohm | 2.0M ohm
2.2 ohm | 22 ohm | 220 ohm | 2.2k ohm | 22k ohm | 220k ohm | 2.2M ohm
2.4 ohm | 24 ohm | 240 ohm | 2.4k ohm | 24k ohm | 240k ohm | 2.4M ohm
2.7 ohm | 27 ohm | 270 ohm | 2.7k ohm | 27k ohm | 270k ohm | 2.7M ohm
3.0 ohm | 30 ohm | 300 ohm | 3.0K ohm | 30K ohm | 300K ohm | 3.0M ohm
3.3 ohm | 33 ohm | 330 ohm | 3.3k ohm | 33k ohm | 330k ohm | 3.3M ohm
3.6 ohm | 36 ohm | 360 ohm | 3.6k ohm | 36k ohm | 360k ohm | 3.6M ohm
3.9 ohm | 39 ohm | 390 ohm | 3.9k ohm | 39k ohm | 390k ohm | 3.9M ohm
4.3 ohm | 43 ohm | 430 ohm | 4.3k ohm | 43K ohm | 430K ohm | 4.3M ohm
4.7 ohm | 47 ohm | 470 ohm | 4.7k ohm | 47k ohm | 470k ohm | 4.7M ohm
5.1 ohm | 51 ohm | 510 ohm | 5.1k ohm | 51k ohm | 510k ohm | 5.1M ohm
5.6 ohm | 56 ohm | 560 ohm | 5.6k ohm | 56k ohm | 560k ohm | 5.6M ohm
6.2 ohm | 62 ohm | 620 ohm | 6.2k ohm | 62K ohm | 620K ohm | 6.2M ohm
6.8 ohm | 68 ohm | 680 ohm | 6.8k ohm | 68k ohm | 680k ohm | 6.8M ohm
7.5 ohm | 75 ohm | 750 ohm | 7.5k ohm | 75k ohm | 750k ohm | 7.5M ohm
8.2 ohm | 82 ohm | 820 ohm | 8.2k ohm | 82k ohm | 820k ohm | 8.2M ohm
9.1 ohm | 91 ohm | 910 ohm | 9.1k ohm | 91k ohm | 910k ohm | 9.1M ohm
#generics #CommonPartsLibrary" | ""
"R3 | R4" | "0603WAF270JT5E" | "2" | "" | "A generic fixed resistor ideal for rapid circuit topology development. Its footprint automatically adapts based on the selected package case code—supporting 0402 | 0603 | 0805 | 1203 | and many other standard SMD packages | as well as axial horizontal and vertical configurations.
Save precious design time by seamlessly add more information to this part (value | footprint | etc.) as it becomes available.
Standard resistor values:
1.0 ohm | 10 ohm | 100 ohm | 1.0k ohm | 10k ohm | 100k ohm | 1.0M ohm
1.1 ohm | 11 ohm | 110 ohm | 1.1k ohm | 11k ohm | 110k ohm | 1.1M ohm
1.2 ohm | 12 ohm | 120 ohm | 1.2k ohm | 12k ohm | 120k ohm | 1.2M ohm
1.3 ohm | 13 ohm | 130 ohm | 1.3k ohm | 13k ohm | 130k ohm | 1.3M ohm
1.5 ohm | 15 ohm | 150 ohm | 1.5k ohm | 15k ohm | 150k ohm | 1.5M ohm
1.6 ohm | 16 ohm | 160 ohm | 1.6k ohm | 16k ohm | 160k ohm | 1.6M ohm
1.8 ohm | 18 ohm | 180 ohm | 1.8K ohm | 18k ohm | 180k ohm | 1.8M ohm
2.0 ohm | 20 ohm | 200 ohm | 2.0k ohm | 20k ohm | 200k ohm | 2.0M ohm
2.2 ohm | 22 ohm | 220 ohm | 2.2k ohm | 22k ohm | 220k ohm | 2.2M ohm
2.4 ohm | 24 ohm | 240 ohm | 2.4k ohm | 24k ohm | 240k ohm | 2.4M ohm
2.7 ohm | 27 ohm | 270 ohm | 2.7k ohm | 27k ohm | 270k ohm | 2.7M ohm
3.0 ohm | 30 ohm | 300 ohm | 3.0K ohm | 30K ohm | 300K ohm | 3.0M ohm
3.3 ohm | 33 ohm | 330 ohm | 3.3k ohm | 33k ohm | 330k ohm | 3.3M ohm
3.6 ohm | 36 ohm | 360 ohm | 3.6k ohm | 36k ohm | 360k ohm | 3.6M ohm
3.9 ohm | 39 ohm | 390 ohm | 3.9k ohm | 39k ohm | 390k ohm | 3.9M ohm
4.3 ohm | 43 ohm | 430 ohm | 4.3k ohm | 43K ohm | 430K ohm | 4.3M ohm
4.7 ohm | 47 ohm | 470 ohm | 4.7k ohm | 47k ohm | 470k ohm | 4.7M ohm
5.1 ohm | 51 ohm | 510 ohm | 5.1k ohm | 51k ohm | 510k ohm | 5.1M ohm
5.6 ohm | 56 ohm | 560 ohm | 5.6k ohm | 56k ohm | 560k ohm | 5.6M ohm
6.2 ohm | 62 ohm | 620 ohm | 6.2k ohm | 62K ohm | 620K ohm | 6.2M ohm
6.8 ohm | 68 ohm | 680 ohm | 6.8k ohm | 68k ohm | 680k ohm | 6.8M ohm
7.5 ohm | 75 ohm | 750 ohm | 7.5k ohm | 75k ohm | 750k ohm | 7.5M ohm
8.2 ohm | 82 ohm | 820 ohm | 8.2k ohm | 82k ohm | 820k ohm | 8.2M ohm
9.1 ohm | 91 ohm | 910 ohm | 9.1k ohm | 91k ohm | 910k ohm | 9.1M ohm
#generics #CommonPartsLibrary" | ""
"R5 | R6" | "0603WAF1001T5E" | "2" | "" | "A generic fixed resistor ideal for rapid circuit topology development. Its footprint automatically adapts based on the selected package case code—supporting 0402 | 0603 | 0805 | 1203 | and many other standard SMD packages | as well as axial horizontal and vertical configurations.
Save precious design time by seamlessly add more information to this part (value | footprint | etc.) as it becomes available.
Standard resistor values:
1.0 ohm | 10 ohm | 100 ohm | 1.0k ohm | 10k ohm | 100k ohm | 1.0M ohm
1.1 ohm | 11 ohm | 110 ohm | 1.1k ohm | 11k ohm | 110k ohm | 1.1M ohm
1.2 ohm | 12 ohm | 120 ohm | 1.2k ohm | 12k ohm | 120k ohm | 1.2M ohm
1.3 ohm | 13 ohm | 130 ohm | 1.3k ohm | 13k ohm | 130k ohm | 1.3M ohm
1.5 ohm | 15 ohm | 150 ohm | 1.5k ohm | 15k ohm | 150k ohm | 1.5M ohm
1.6 ohm | 16 ohm | 160 ohm | 1.6k ohm | 16k ohm | 160k ohm | 1.6M ohm
1.8 ohm | 18 ohm | 180 ohm | 1.8K ohm | 18k ohm | 180k ohm | 1.8M ohm
2.0 ohm | 20 ohm | 200 ohm | 2.0k ohm | 20k ohm | 200k ohm | 2.0M ohm
2.2 ohm | 22 ohm | 220 ohm | 2.2k ohm | 22k ohm | 220k ohm | 2.2M ohm
2.4 ohm | 24 ohm | 240 ohm | 2.4k ohm | 24k ohm | 240k ohm | 2.4M ohm
2.7 ohm | 27 ohm | 270 ohm | 2.7k ohm | 27k ohm | 270k ohm | 2.7M ohm
3.0 ohm | 30 ohm | 300 ohm | 3.0K ohm | 30K ohm | 300K ohm | 3.0M ohm
3.3 ohm | 33 ohm | 330 ohm | 3.3k ohm | 33k ohm | 330k ohm | 3.3M ohm
3.6 ohm | 36 ohm | 360 ohm | 3.6k ohm | 36k ohm | 360k ohm | 3.6M ohm
3.9 ohm | 39 ohm | 390 ohm | 3.9k ohm | 39k ohm | 390k ohm | 3.9M ohm
4.3 ohm | 43 ohm | 430 ohm | 4.3k ohm | 43K ohm | 430K ohm | 4.3M ohm
4.7 ohm | 47 ohm | 470 ohm | 4.7k ohm | 47k ohm | 470k ohm | 4.7M ohm
5.1 ohm | 51 ohm | 510 ohm | 5.1k ohm | 51k ohm | 510k ohm | 5.1M ohm
5.6 ohm | 56 ohm | 560 ohm | 5.6k ohm | 56k ohm | 560k ohm | 5.6M ohm
6.2 ohm | 62 ohm | 620 ohm | 6.2k ohm | 62K ohm | 620K ohm | 6.2M ohm
6.8 ohm | 68 ohm | 680 ohm | 6.8k ohm | 68k ohm | 680k ohm | 6.8M ohm
7.5 ohm | 75 ohm | 750 ohm | 7.5k ohm | 75k ohm | 750k ohm | 7.5M ohm
8.2 ohm | 82 ohm | 820 ohm | 8.2k ohm | 82k ohm | 820k ohm | 8.2M ohm
9.1 ohm | 91 ohm | 910 ohm | 9.1k ohm | 91k ohm | 910k ohm | 9.1M ohm
#generics #CommonPartsLibrary" | ""
"R14 | R15 | R7 | R8 | R9" | "0603WAF1002T5E" | "5" | "" | "A generic fixed resistor ideal for rapid circuit topology development. Its footprint automatically adapts based on the selected package case code—supporting 0402 | 0603 | 0805 | 1203 | and many other standard SMD packages | as well as axial horizontal and vertical configurations.
Save precious design time by seamlessly add more information to this part (value | footprint | etc.) as it becomes available.
Standard resistor values:
1.0 ohm | 10 ohm | 100 ohm | 1.0k ohm | 10k ohm | 100k ohm | 1.0M ohm
1.1 ohm | 11 ohm | 110 ohm | 1.1k ohm | 11k ohm | 110k ohm | 1.1M ohm
1.2 ohm | 12 ohm | 120 ohm | 1.2k ohm | 12k ohm | 120k ohm | 1.2M ohm
1.3 ohm | 13 ohm | 130 ohm | 1.3k ohm | 13k ohm | 130k ohm | 1.3M ohm
1.5 ohm | 15 ohm | 150 ohm | 1.5k ohm | 15k ohm | 150k ohm | 1.5M ohm
1.6 ohm | 16 ohm | 160 ohm | 1.6k ohm | 16k ohm | 160k ohm | 1.6M ohm
1.8 ohm | 18 ohm | 180 ohm | 1.8K ohm | 18k ohm | 180k ohm | 1.8M ohm
2.0 ohm | 20 ohm | 200 ohm | 2.0k ohm | 20k ohm | 200k ohm | 2.0M ohm
2.2 ohm | 22 ohm | 220 ohm | 2.2k ohm | 22k ohm | 220k ohm | 2.2M ohm
2.4 ohm | 24 ohm | 240 ohm | 2.4k ohm | 24k ohm | 240k ohm | 2.4M ohm
2.7 ohm | 27 ohm | 270 ohm | 2.7k ohm | 27k ohm | 270k ohm | 2.7M ohm
3.0 ohm | 30 ohm | 300 ohm | 3.0K ohm | 30K ohm | 300K ohm | 3.0M ohm
3.3 ohm | 33 ohm | 330 ohm | 3.3k ohm | 33k ohm | 330k ohm | 3.3M ohm
3.6 ohm | 36 ohm | 360 ohm | 3.6k ohm | 36k ohm | 360k ohm | 3.6M ohm
3.9 ohm | 39 ohm | 390 ohm | 3.9k ohm | 39k ohm | 390k ohm | 3.9M ohm
4.3 ohm | 43 ohm | 430 ohm | 4.3k ohm | 43K ohm | 430K ohm | 4.3M ohm
4.7 ohm | 47 ohm | 470 ohm | 4.7k ohm | 47k ohm | 470k ohm | 4.7M ohm
5.1 ohm | 51 ohm | 510 ohm | 5.1k ohm | 51k ohm | 510k ohm | 5.1M ohm
5.6 ohm | 56 ohm | 560 ohm | 5.6k ohm | 56k ohm | 560k ohm | 5.6M ohm
6.2 ohm | 62 ohm | 620 ohm | 6.2k ohm | 62K ohm | 620K ohm | 6.2M ohm
6.8 ohm | 68 ohm | 680 ohm | 6.8k ohm | 68k ohm | 680k ohm | 6.8M ohm
7.5 ohm | 75 ohm | 750 ohm | 7.5k ohm | 75k ohm | 750k ohm | 7.5M ohm
8.2 ohm | 82 ohm | 820 ohm | 8.2k ohm | 82k ohm | 820k ohm | 8.2M ohm
9.1 ohm | 91 ohm | 910 ohm | 9.1k ohm | 91k ohm | 910k ohm | 9.1M ohm
#generics #CommonPartsLibrary" | ""
"SW1 | SW2" | "B3U-3000P" | "2" | "" | "Tactile Switch SPST-NO Side Actuated Surface Mount | Right Angle #commonpartslibrary
#switch
#tactile
#spst" | ""
"SW3 | SW4" | "TS-1088-AR02016" | "2" | "" | "50mA 4mm 100MΩ 100 | 000 Times 12V 160gf 3mm 2mm Round Button Vertical welding SPST SMD Tactile Switches ROHS
Tactile Switches
TS-1088-AR02016
SW-SMD_L3.9-W3.0-P4.45
LCSC Part Number: C720477
JLCPCB Part Class: Extended Part
Manufactured by XUNPU(讯普) momentary tactile switch | SMD
6 mm tactile push button | through-hole
SPST on/off mechanical switch
momentary pushbutton for BOOT / RESET / PTT" | ""
"U1" | "RP2040" | "1" | "" | "A microcontroller by Raspberry Pi
RP2040 ARM Cortex-M0+ USB
QFN*1EP*7x7mm?P0.4mm* " | ""
"U2" | "W25Q16JVUXIQ" | "1" | "" | "SPI Flash Serial Flash Memory with Dual/Quad SPI
The W25Q16JVUXIQ is a 16-Mbit (2-MByte) Serial NOR Flash memory device from Winbond. It is designed for embedded systems that require non-volatile code and data storage with minimal pin count | low power consumption | and high-speed access. The device supports standard SPI | Dual SPI | and Quad SPI interfaces | making it suitable for firmware storage | boot memory | IoT devices | microcontrollers | consumer electronics | and execute-in-place (XIP) applications.
Key Features
16-Mbit (2-MByte) Flash Memory Capacity
Operating Voltage: 2.7 V to 3.6 V
Standard SPI | Dual SPI | and Quad SPI Interface Support
Maximum SPI Clock Frequency: 133 MHz
Equivalent Data Transfer Rates:
266 MHz (Dual SPI)
532 MHz (Quad SPI)
Continuous Read and XIP (Execute-In-Place) Capability
4 KB Sector Erase | 32 KB Block Erase | 64 KB Block Erase | and Chip Erase
256-Byte Programmable Page Size
Minimum 100 | 000 Program/Erase Cycles per Sector
More Than 20 Years Data Retention
Ultra-Low Power Consumption
Typical power-down current below 1 µA
64-Bit Unique Serial Number
Three 256-Byte Security Registers with OTP Protection
JEDEC ID and SFDP Support
Software and Hardware Write Protection
Operating Temperature Options up to +85°C and +105°C
Compact 8-Pad USON Package (2 mm × 3 mm) suitable for space-constrained designs
#CommonPartsLibrary #IntegratedCircuit #Memory" | ""
"U3" | "MAX98357AETE+T" | "1" | "" | "3.2Wx2@4Ω TQFN-16-EP(3x3) Audio Power OpAmps ROHS
Imported from Samacsys
QFN50P300X300X80-17N
https://datasheets.maximintegrated.com/en/ds/MAX98357A-MAX98357B.pdf
Audio Amplifiers Digital Input Class D Amplifier
0.8
Analog Devices
MAX98357AETE+T
700-MAX98357AETE+T
https://www.mouser.co.uk/ProductDetail/Analog-Devices-Maxim-Integrated/MAX98357AETE%2bT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
MAX98357AETE+T
https://www.arrow.com/en/products/max98357aetet/analog-devices?region=nac
#part" | ""
"U5" | "MCP1825T-3302E/DC" | "1" | "" | "Linear Voltage Regulator IC Positive Fixed 1 Output 500mA SOT-223-5
Linear Voltage Regulator (LDO) providing a fixed 3.3 V output with up to 500 mA output current from an input voltage range of 2.3 V to 6.0 V. It features low dropout voltage | stable operation with ceramic output capacitors | current limiting | short-circuit protection | and overtemperature protection | making it suitable for low-voltage power regulation applications.
#LDO #LinearVoltageRegulator #FixedOutput #3V3 #500mA #LowDropout #PowerManagement #Microchip" | ""
"Y1" | "ABM8-272-T3" | "1" | "" | "Crystal | 12 MHz | SMD | 3.2mm x 2.5mm | 30 ppm | 10 pF | 30 ppm | ABM8 Series
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

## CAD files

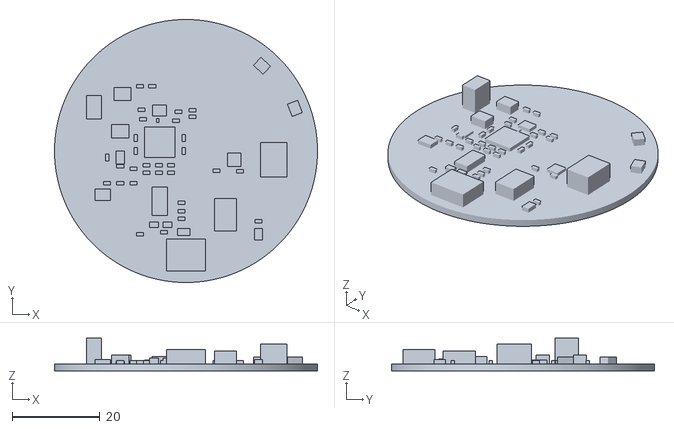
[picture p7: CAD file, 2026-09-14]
mechanical/claude-handset-assembly.stl
60.0 x 60.0 x 7.50

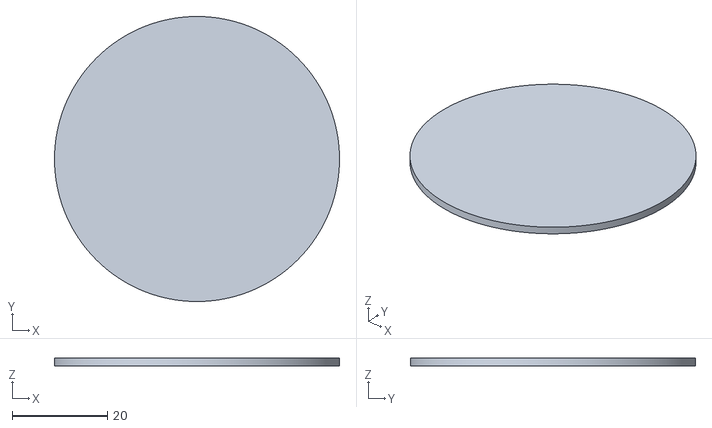
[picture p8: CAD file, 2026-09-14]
mechanical/claude-handset-board.stl
60.0 x 60.0 x 1.60

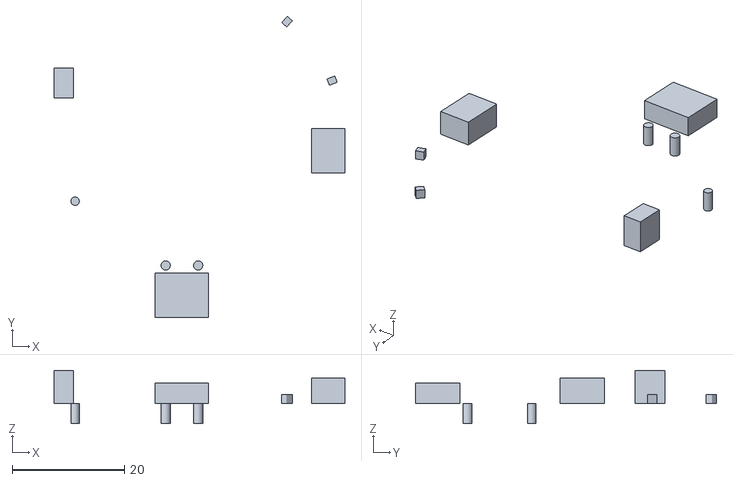
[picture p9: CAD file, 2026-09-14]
mechanical/claude-handset-keepouts.stl
51.8 x 53.6 x 9.50

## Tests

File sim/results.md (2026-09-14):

# Wiring simulation results

Board: Claude Handset #3cf75256, netlist from asbuilt_netlist.json

**142 checks passed, 0 failed, 1 warnings (placement, not wiring).**

## Netlist: as-built copper vs intended

| Check | Result | Detail |
|---|---|---|
| no orphan pads / shorts / split nets | PASS | all pads on the intended nets |
| RP2040 pin numbering matches netlist labels | PASS | 56 pins identified from pad geometry |
| GPIO2 = I2S_BCLK (per project description) | PASS | GPIO2 is on I2S_BCLK |
| GPIO3 = I2S_LRCLK (per project description) | PASS | GPIO3 is on I2S_LRCLK |
| GPIO4 = I2S_DAC_DATA (per project description) | PASS | GPIO4 is on I2S_DAC_DATA |
| GPIO5 = PDM_DATA (per project description) | PASS | GPIO5 is on PDM_DATA |
| GPIO6 = PDM_CLK (per project description) | PASS | GPIO6 is on PDM_CLK |
| GPIO21 = AMP_SD_MODE (per project description) | PASS | GPIO21 is on AMP_SD_MODE |
| GPIO7 assignment | PASS | GPIO7 is on F13_BTN_N |
| GPIO8 assignment | PASS | GPIO8 is on F14_BTN_N |
| GPIO9 assignment | PASS | GPIO9 is on 3V3_PWRGD |
| all RP2040 IOVDD pins on one net | PASS | IOVDD pins: {'3V3'} |
| all RP2040 DVDD pins on one net | PASS | DVDD pins: {'1V1_CORE'} |
| RP2040 exposed pad on GND | PASS | EP is on GND |
| TESTEN tied to GND | PASS | TESTEN on GND |
| no unpowered IC supply pins | PASS | U2/U3/MK1/U5 supply pins connected |

## Wiring paths (2-terminal resistance, ICs unpowered)

| Check | Result | Detail |
|---|---|---|
| USB D+ : J1.DP1 -> D1 -> R3 -> RP2040 USB_DP | PASS | measured 27 Ω, expected 27 Ω |
| USB D- : J1.DN1 -> D1 -> R4 -> RP2040 USB_DM | PASS | measured 27 Ω, expected 27 Ω |
| USB D+ both connector pins tied (DP1-DP2) | PASS | measured 0.0 mΩ, expected 0.0 mΩ |
| USB D- both connector pins tied (DN1-DN2) | PASS | measured 0.0 mΩ, expected 0.0 mΩ |
| CC1 pull-down to GND (R1) | PASS | measured 5.1e+03 Ω, expected 5.1e+03 Ω |
| CC2 pull-down to GND (R2) | PASS | measured 5.1e+03 Ω, expected 5.1e+03 Ω |
| VBUS: J1.VBUS -> F1 -> VBUS_5V (fuse) | PASS | measured 0.5 Ω, expected 0.5 Ω |
| VBUS_5V -> amp VDD | PASS | measured 0.0 mΩ, expected 0.0 mΩ |
| VBUS_5V -> LDO SHDN (always enabled) | PASS | measured 0.0 mΩ, expected 0.0 mΩ |
| 3V3 -> FB1 -> mic VDD | PASS | measured 0.8 Ω, expected 0.8 Ω |
| 3V3 -> flash VCC | PASS | measured 0.0 mΩ, expected 0.0 mΩ |
| 3V3 -> SWD header pin 1 | PASS | measured 0.0 mΩ, expected 0.0 mΩ |
| RP2040 VREG_VOUT -> DVDD (1V1 core) | PASS | measured 0.0 mΩ, expected 0.0 mΩ |
| XIN -> Y1 | PASS | measured 0.0 mΩ, expected 0.0 mΩ |
| XOUT -> R5 -> Y1 | PASS | measured 1e+03 Ω, expected 1e+03 Ω |
| QSPI_SS -> R6 -> flash CS | PASS | measured 1e+03 Ω, expected 1e+03 Ω |
| flash CS pull-up R7 to 3V3 | PASS | measured 1e+04 Ω, expected 1e+04 Ω |
| QSPI_SCLK -> flash CLK | PASS | measured 0.0 mΩ, expected 0.0 mΩ |
| QSPI_SD0 -> flash DI (IO0) | PASS | measured 0.0 mΩ, expected 0.0 mΩ |
| QSPI_SD1 -> flash DO (IO1) | PASS | measured 0.0 mΩ, expected 0.0 mΩ |
| QSPI_SD2 -> flash WP# (IO2) | PASS | measured 0.0 mΩ, expected 0.0 mΩ |
| QSPI_SD3 -> flash HOLD (IO3) | PASS | measured 0.0 mΩ, expected 0.0 mΩ |
| GPIO2 -> amp BCLK | PASS | measured 0.0 mΩ, expected 0.0 mΩ |
| GPIO3 -> amp LRCLK | PASS | measured 0.0 mΩ, expected 0.0 mΩ |
| GPIO4 -> amp DIN | PASS | measured 0.0 mΩ, expected 0.0 mΩ |
| GPIO21 -> amp SD_MODE | PASS | measured 0.0 mΩ, expected 0.0 mΩ |
| amp OUTP -> J3 pin 1 | PASS | measured 0.0 mΩ, expected 0.0 mΩ |
| amp OUTN -> J3 pin 2 | PASS | measured 0.0 mΩ, expected 0.0 mΩ |
| speaker terminals not grounded (J3.1 -> GND) | PASS | measured open (>1 MΩ), expected open |
| speaker terminals not grounded (J3.2 -> GND) | PASS | measured open (>1 MΩ), expected open |
| GPIO6 -> mic CLK | PASS | measured 0.0 mΩ, expected 0.0 mΩ |
| GPIO5 -> mic DATA | PASS | measured 0.0 mΩ, expected 0.0 mΩ |
| mic SELECT tied low | PASS | measured 0.0 mΩ, expected 0.0 mΩ |
| SWD header: SWDIO | PASS | measured 0.0 mΩ, expected 0.0 mΩ |
| SWD header: SWCLK | PASS | measured 0.0 mΩ, expected 0.0 mΩ |
| SWD header: RUN | PASS | measured 0.0 mΩ, expected 0.0 mΩ |
| SWD header: GND | PASS | measured 0.0 mΩ, expected 0.0 mΩ |
| RUN pull-up R8 to 3V3 | PASS | measured 1e+04 Ω, expected 1e+04 Ω |
| PWRGD pull-up R9 to 3V3 | PASS | measured 1e+04 Ω, expected 1e+04 Ω |
| PWRGD -> GPIO9 | PASS | measured 0.0 mΩ, expected 0.0 mΩ |
| F13 pull-up R14 to 3V3 | PASS | measured 1e+04 Ω, expected 1e+04 Ω |
| F14 pull-up R15 to 3V3 | PASS | measured 1e+04 Ω, expected 1e+04 Ω |
| no DC path 3V3 -> GND with everything off | PASS | measured open (>1 MΩ), expected open |
| no DC path VBUS_5V -> GND with everything off | PASS | measured open (>1 MΩ), expected open |
| no DC path 1V1 -> GND with everything off | PASS | measured open (>1 MΩ), expected open |
| USB D+ isolated from D- | PASS | measured open (>1 MΩ), expected open |
| USB D+ isolated from GND | PASS | measured open (>1 MΩ), expected open |
| SW1 shorts F13_BTN_N to GND | PASS | closed: 50.0 mΩ; open: open (>1 MΩ) |
| SW2 shorts F14_BTN_N to GND | PASS | closed: 50.0 mΩ; open: open (>1 MΩ) |
| SW3 shorts MCU_RUN to GND | PASS | closed: 50.0 mΩ; open: open (>1 MΩ) |
| SW4 shorts QSPI_CS_FLASH to GND | PASS | closed: 50.0 mΩ; open: open (>1 MΩ) |

## Decoupling capacitors (net + distance to the pin they serve)

| Check | Result | Detail |
|---|---|---|
| RP2040 pin 1 IOVDD (3V3) | PASS | nearest cap C5 100 nF at 2.07 mm |
| RP2040 pin 10 IOVDD (3V3) | PASS | nearest cap C4 100 nF at 2.20 mm |
| RP2040 pin 22 IOVDD (3V3) | WARN | nearest cap C6 100 nF at 3.45 mm |
| RP2040 pin 33 IOVDD (3V3) | PASS | nearest cap C7 100 nF at 2.20 mm |
| RP2040 pin 42 IOVDD (3V3) | PASS | nearest cap C8 100 nF at 2.07 mm |
| RP2040 pin 49 IOVDD (3V3) | PASS | nearest cap C15 100 nF at 2.68 mm |
| RP2040 pin 48 USB_VDD (3V3) | PASS | nearest cap C15 100 nF at 3.00 mm |
| RP2040 pin 43 ADC_AVDD (3V3) | PASS | nearest cap C13 1000 nF at 2.12 mm |
| RP2040 pin 44 VREG_VIN (3V3) | PASS | nearest cap C13 1000 nF at 2.36 mm |
| RP2040 pin 23 DVDD (1V1_CORE) | PASS | nearest cap C11 100 nF at 1.07 mm |
| RP2040 pin 50 DVDD (1V1_CORE) | PASS | nearest cap C14 1000 nF at 2.12 mm |
| RP2040 pin 45 VREG_VOUT (1V1_CORE) | PASS | nearest cap C14 1000 nF at 1.95 mm |
| flash VCC (3V3) | PASS | nearest cap C17 100 nF at 1.49 mm |
| amp VDD (VBUS_5V) | PASS | nearest cap C24 100 nF at 1.18 mm |
| mic VDD (filtered) (MIC_3V3_FILT) | PASS | nearest cap C28 100 nF at 1.65 mm |
| LDO input (VBUS_5V) | PASS | nearest cap C2 10000 nF at 2.50 mm |
| LDO output (3V3) | PASS | nearest cap C3 10000 nF at 2.34 mm |
| crystal load caps 27 pF on XIN and XOUT sides | PASS | C12 on {'GND', 'XOSC_XI'}, C18 on {'GND', 'XOSC_XO'} |
| RUN reset RC (R8 + C20) | PASS | C20 on {'GND', 'MCU_RUN'}; tau = 1.0 ms |

## DC scenarios

| Check | Result | Detail |
|---|---|---|
| USB plugged, idle: V(USB_VBUS_RAW) | PASS | 4.994 V (expected 4.95..5.0 V) |
| USB plugged, idle: V(VBUS_5V) | PASS | 4.967 V (expected 4.9..5.0 V) |
| USB plugged, idle: V(3V3) | PASS | 3.297 V (expected 3.25..3.35 V) |
| USB plugged, idle: V(1V1_CORE) | PASS | 1.096 V (expected 1.05..1.15 V) |
| USB plugged, idle: V(MIC_3V3_FILT) | PASS | 3.297 V (expected 3.25..3.35 V) |
| USB plugged, idle: V(3V3_PWRGD) | PASS | 3.297 V (expected 3.2..3.35 V) |
| USB plugged, idle: V(MCU_RUN) | PASS | 3.297 V (expected 3.2..3.35 V) |
| USB plugged, idle: V(QSPI_CS_FLASH) | PASS | 3.297 V (expected 3.2..3.35 V) |
| USB plugged, idle: V(QSPI_SS_MCU) | PASS | 3.297 V (expected 3.2..3.35 V) |
| USB plugged, idle: V(F13_BTN_N) | PASS | 3.297 V (expected 3.2..3.35 V) |
| USB plugged, idle: V(F14_BTN_N) | PASS | 3.297 V (expected 3.2..3.35 V) |
| USB plugged, idle: V(AMP_SD_MODE) | PASS | 0.000 V (expected 0..0.05 V) |
| USB plugged, idle: V(USB_CC1) | PASS | 0.000 V (expected 0..0.01 V) |
| USB plugged, idle: V(USB_CC2) | PASS | 0.000 V (expected 0..0.01 V) |
| USB plugged, idle: fuse current below 0.5 A hold | PASS | 55 mA through F1 |
| USB plugged, idle: LDO within 500 mA and dissipation sane | PASS | LDO out 55.2 mA, dissipation 92 mW |
| F13 button pressed: V(3V3) | PASS | 3.297 V (expected 3.25..3.35 V) |
| F13 button pressed: V(F13_BTN_N) | PASS | 0.000 V (expected 0..0.05 V) |
| F13 button pressed: V(F14_BTN_N) | PASS | 3.297 V (expected 3.2..3.35 V) |
| F13 button pressed: fuse current below 0.5 A hold | PASS | 56 mA through F1 |
| F13 button pressed: LDO within 500 mA and dissipation sane | PASS | LDO out 55.5 mA, dissipation 93 mW |
| F14 button pressed: V(3V3) | PASS | 3.297 V (expected 3.25..3.35 V) |
| F14 button pressed: V(F13_BTN_N) | PASS | 3.297 V (expected 3.2..3.35 V) |
| F14 button pressed: V(F14_BTN_N) | PASS | 0.000 V (expected 0..0.05 V) |
| F14 button pressed: fuse current below 0.5 A hold | PASS | 56 mA through F1 |
| F14 button pressed: LDO within 500 mA and dissipation sane | PASS | LDO out 55.5 mA, dissipation 93 mW |
| SW3 pressed (RUN low = reset): V(3V3) | PASS | 3.297 V (expected 3.25..3.35 V) |
| SW3 pressed (RUN low = reset): V(MCU_RUN) | PASS | 0.000 V (expected 0..0.05 V) |
| SW3 pressed (RUN low = reset): V(QSPI_CS_FLASH) | PASS | 3.297 V (expected 3.2..3.35 V) |
| SW3 pressed (RUN low = reset): fuse current below 0.5 A hold | PASS | 56 mA through F1 |
| SW3 pressed (RUN low = reset): LDO within 500 mA and dissipation sane | PASS | LDO out 55.5 mA, dissipation 93 mW |
| SW4 pressed (flash CS low = BOOTSEL): V(MCU_RUN) | PASS | 3.297 V (expected 3.2..3.35 V) |
| SW4 pressed (flash CS low = BOOTSEL): V(QSPI_CS_FLASH) | PASS | 0.000 V (expected 0..0.05 V) |
| SW4 pressed (flash CS low = BOOTSEL): V(QSPI_SS_MCU) | PASS | 0.058 V (expected 0..0.4 V) |
| SW4 pressed (flash CS low = BOOTSEL): fuse current below 0.5 A hold | PASS | 56 mA through F1 |
| SW4 pressed (flash CS low = BOOTSEL): LDO within 500 mA and dissipation sane | PASS | LDO out 55.6 mA, dissipation 93 mW |
| Debugger holds RUN low via J4: V(3V3) | PASS | 3.297 V (expected 3.25..3.35 V) |
| Debugger holds RUN low via J4: V(MCU_RUN) | PASS | 0.000 V (expected 0..0.05 V) |
| Debugger holds RUN low via J4: fuse current below 0.5 A hold | PASS | 56 mA through F1 |
| Debugger holds RUN low via J4: LDO within 500 mA and dissipation sane | PASS | LDO out 55.5 mA, dissipation 93 mW |
| Amp enabled, 1 W playing (GPIO21 high): V(VBUS_5V) | PASS | 4.828 V (expected 4.7..5.0 V) |
| Amp enabled, 1 W playing (GPIO21 high): V(3V3) | PASS | 3.297 V (expected 3.25..3.35 V) |
| Amp enabled, 1 W playing (GPIO21 high): V(AMP_SD_MODE) | PASS | 3.296 V (expected 3.0..3.35 V) |
| Amp enabled, 1 W playing (GPIO21 high): fuse current below 0.5 A hold | PASS | 287 mA through F1 |
| Amp enabled, 1 W playing (GPIO21 high): LDO within 500 mA and dissipation sane | PASS | LDO out 55.2 mA, dissipation 84 mW |
| Amp disabled (GPIO21 low): V(AMP_SD_MODE) | PASS | 0.000 V (expected 0..0.05 V) |
| Amp disabled (GPIO21 low): fuse current below 0.5 A hold | PASS | 55 mA through F1 |
| Amp disabled (GPIO21 low): LDO within 500 mA and dissipation sane | PASS | LDO out 55.2 mA, dissipation 92 mW |
| USB brown-out to 3.0 V: V(3V3) | PASS | 2.865 V (expected 2.7..3.0 V) |
| USB brown-out to 3.0 V: V(3V3_PWRGD) | PASS | 0.017 V (expected 0..0.2 V) |
| USB brown-out to 3.0 V: fuse current below 0.5 A hold | PASS | 54 mA through F1 |
| USB brown-out to 3.0 V: LDO within 500 mA and dissipation sane | PASS | LDO out 53.6 mA, dissipation 6 mW |
| USB unplugged: V(VBUS_5V) | PASS | 0.000 V (expected 0..0.01 V) |
| USB unplugged: V(3V3) | PASS | 0.000 V (expected 0..0.01 V) |
| USB unplugged: V(1V1_CORE) | PASS | 0.000 V (expected 0..0.01 V) |
| USB unplugged: V(3V3_PWRGD) | PASS | 0.000 V (expected 0..0.01 V) |
| USB unplugged: V(MCU_RUN) | PASS | 0.000 V (expected 0..0.01 V) |

## Scenario operating points

### USB plugged, idle

| Net | V | expected | ok |
|---|---|---|---|
| USB_VBUS_RAW | 4.994 | 4.95..5.0 | ok |
| VBUS_5V | 4.967 | 4.9..5.0 | ok |
| 3V3 | 3.297 | 3.25..3.35 | ok |
| 1V1_CORE | 1.096 | 1.05..1.15 | ok |
| MIC_3V3_FILT | 3.297 | 3.25..3.35 | ok |
| 3V3_PWRGD | 3.297 | 3.2..3.35 | ok |
| MCU_RUN | 3.297 | 3.2..3.35 | ok |
| QSPI_CS_FLASH | 3.297 | 3.2..3.35 | ok |
| QSPI_SS_MCU | 3.297 | 3.2..3.35 | ok |
| F13_BTN_N | 3.297 | 3.2..3.35 | ok |
| F14_BTN_N | 3.297 | 3.2..3.35 | ok |
| AMP_SD_MODE | 0.000 | 0..0.05 | ok |
| USB_CC1 | 0.000 | 0..0.01 | ok |
| USB_CC2 | 0.000 | 0..0.01 | ok |
| SPKR_P | 0.000 |  | ok |
| SPKR_N | 0.000 |  | ok |

fuse 55.4 mA, LDO out 55.2 mA (92 mW), RP2040 core reg 39.9 mA, I(R14) -0 µA, I(R7) -0 µA, I(R9) -0 µA

### F13 button pressed

| Net | V | expected | ok |
|---|---|---|---|
| USB_VBUS_RAW | 4.994 |  | ok |
| VBUS_5V | 4.967 |  | ok |
| 3V3 | 3.297 | 3.25..3.35 | ok |
| 1V1_CORE | 1.096 |  | ok |
| MIC_3V3_FILT | 3.297 |  | ok |
| 3V3_PWRGD | 3.297 |  | ok |
| MCU_RUN | 3.297 |  | ok |
| QSPI_CS_FLASH | 3.297 |  | ok |
| QSPI_SS_MCU | 3.297 |  | ok |
| F13_BTN_N | 0.000 | 0..0.05 | ok |
| F14_BTN_N | 3.297 | 3.2..3.35 | ok |
| AMP_SD_MODE | 0.000 |  | ok |
| USB_CC1 | 0.000 |  | ok |
| USB_CC2 | 0.000 |  | ok |
| SPKR_P | 0.000 |  | ok |
| SPKR_N | 0.000 |  | ok |

fuse 55.7 mA, LDO out 55.5 mA (93 mW), RP2040 core reg 39.9 mA, I(R14) -330 µA, I(R7) -0 µA, I(R9) -0 µA

### F14 button pressed

| Net | V | expected | ok |
|---|---|---|---|
| USB_VBUS_RAW | 4.994 |  | ok |
| VBUS_5V | 4.967 |  | ok |
| 3V3 | 3.297 | 3.25..3.35 | ok |
| 1V1_CORE | 1.096 |  | ok |
| MIC_3V3_FILT | 3.297 |  | ok |
| 3V3_PWRGD | 3.297 |  | ok |
| MCU_RUN | 3.297 |  | ok |
| QSPI_CS_FLASH | 3.297 |  | ok |
| QSPI_SS_MCU | 3.297 |  | ok |
| F13_BTN_N | 3.297 | 3.2..3.35 | ok |
| F14_BTN_N | 0.000 | 0..0.05 | ok |
| AMP_SD_MODE | 0.000 |  | ok |
| USB_CC1 | 0.000 |  | ok |
| USB_CC2 | 0.000 |  | ok |
| SPKR_P | 0.000 |  | ok |
| SPKR_N | 0.000 |  | ok |

fuse 55.7 mA, LDO out 55.5 mA (93 mW), RP2040 core reg 39.9 mA, I(R14) -0 µA, I(R7) -0 µA, I(R9) -0 µA

### SW3 pressed (RUN low = reset)

| Net | V | expected | ok |
|---|---|---|---|
| USB_VBUS_RAW | 4.994 |  | ok |
| VBUS_5V | 4.967 |  | ok |
| 3V3 | 3.297 | 3.25..3.35 | ok |
| 1V1_CORE | 1.096 |  | ok |
| MIC_3V3_FILT | 3.297 |  | ok |
| 3V3_PWRGD | 3.297 |  | ok |
| MCU_RUN | 0.000 | 0..0.05 | ok |
| QSPI_CS_FLASH | 3.297 | 3.2..3.35 | ok |
| QSPI_SS_MCU | 3.297 |  | ok |
| F13_BTN_N | 3.297 |  | ok |
| F14_BTN_N | 3.297 |  | ok |
| AMP_SD_MODE | 0.000 |  | ok |
| USB_CC1 | 0.000 |  | ok |
| USB_CC2 | 0.000 |  | ok |
| SPKR_P | 0.000 |  | ok |
| SPKR_N | 0.000 |  | ok |

fuse 55.7 mA, LDO out 55.5 mA (93 mW), RP2040 core reg 39.9 mA, I(R14) -0 µA, I(R7) -0 µA, I(R9) -0 µA

### SW4 pressed (flash CS low = BOOTSEL)

| Net | V | expected | ok |
|---|---|---|---|
| USB_VBUS_RAW | 4.994 |  | ok |
| VBUS_5V | 4.967 |  | ok |
| 3V3 | 3.297 |  | ok |
| 1V1_CORE | 1.096 |  | ok |
| MIC_3V3_FILT | 3.297 |  | ok |
| 3V3_PWRGD | 3.297 |  | ok |
| MCU_RUN | 3.297 | 3.2..3.35 | ok |
| QSPI_CS_FLASH | 0.000 | 0..0.05 | ok |
| QSPI_SS_MCU | 0.058 | 0..0.4 | ok |
| F13_BTN_N | 3.297 |  | ok |
| F14_BTN_N | 3.297 |  | ok |
| AMP_SD_MODE | 0.000 |  | ok |
| USB_CC1 | 0.000 |  | ok |
| USB_CC2 | 0.000 |  | ok |
| SPKR_P | 0.000 |  | ok |
| SPKR_N | 0.000 |  | ok |

fuse 55.8 mA, LDO out 55.6 mA (93 mW), RP2040 core reg 39.9 mA, I(R14) -0 µA, I(R7) -330 µA, I(R9) -0 µA

### Debugger holds RUN low via J4

| Net | V | expected | ok |
|---|---|---|---|
| USB_VBUS_RAW | 4.994 |  | ok |
| VBUS_5V | 4.967 |  | ok |
| 3V3 | 3.297 | 3.25..3.35 | ok |
| 1V1_CORE | 1.096 |  | ok |
| MIC_3V3_FILT | 3.297 |  | ok |
| 3V3_PWRGD | 3.297 |  | ok |
| MCU_RUN | 0.000 | 0..0.05 | ok |
| QSPI_CS_FLASH | 3.297 |  | ok |
| QSPI_SS_MCU | 3.297 |  | ok |
| F13_BTN_N | 3.297 |  | ok |
| F14_BTN_N | 3.297 |  | ok |
| AMP_SD_MODE | 0.000 |  | ok |
| USB_CC1 | 0.000 |  | ok |
| USB_CC2 | 0.000 |  | ok |
| SPKR_P | 0.000 |  | ok |
| SPKR_N | 0.000 |  | ok |

fuse 55.7 mA, LDO out 55.5 mA (93 mW), RP2040 core reg 39.9 mA, I(R14) -0 µA, I(R7) -0 µA, I(R9) -0 µA

### Amp enabled, 1 W playing (GPIO21 high)

| Net | V | expected | ok |
|---|---|---|---|
| USB_VBUS_RAW | 4.971 |  | ok |
| VBUS_5V | 4.828 | 4.7..5.0 | ok |
| 3V3 | 3.297 | 3.25..3.35 | ok |
| 1V1_CORE | 1.096 |  | ok |
| MIC_3V3_FILT | 3.297 |  | ok |
| 3V3_PWRGD | 3.297 |  | ok |
| MCU_RUN | 3.297 |  | ok |
| QSPI_CS_FLASH | 3.297 |  | ok |
| QSPI_SS_MCU | 3.297 |  | ok |
| F13_BTN_N | 3.297 |  | ok |
| F14_BTN_N | 3.297 |  | ok |
| AMP_SD_MODE | 3.296 | 3.0..3.35 | ok |
| USB_CC1 | 0.000 |  | ok |
| USB_CC2 | 0.000 |  | ok |
| SPKR_P | 0.000 |  | ok |
| SPKR_N | 0.000 |  | ok |

fuse 287.0 mA, LDO out 55.2 mA (84 mW), RP2040 core reg 39.9 mA, I(R14) -0 µA, I(R7) -0 µA, I(R9) -0 µA

### Amp disabled (GPIO21 low)

| Net | V | expected | ok |
|---|---|---|---|
| USB_VBUS_RAW | 4.994 |  | ok |
| VBUS_5V | 4.967 |  | ok |
| 3V3 | 3.297 |  | ok |
| 1V1_CORE | 1.096 |  | ok |
| MIC_3V3_FILT | 3.297 |  | ok |
| 3V3_PWRGD | 3.297 |  | ok |
| MCU_RUN | 3.297 |  | ok |
| QSPI_CS_FLASH | 3.297 |  | ok |
| QSPI_SS_MCU | 3.297 |  | ok |
| F13_BTN_N | 3.297 |  | ok |
| F14_BTN_N | 3.297 |  | ok |
| AMP_SD_MODE | 0.000 | 0..0.05 | ok |
| USB_CC1 | 0.000 |  | ok |
| USB_CC2 | 0.000 |  | ok |
| SPKR_P | 0.000 |  | ok |
| SPKR_N | 0.000 |  | ok |

fuse 55.4 mA, LDO out 55.2 mA (92 mW), RP2040 core reg 39.9 mA, I(R14) -0 µA, I(R7) -0 µA, I(R9) -0 µA

### USB brown-out to 3.0 V

| Net | V | expected | ok |
|---|---|---|---|
| USB_VBUS_RAW | 2.995 |  | ok |
| VBUS_5V | 2.968 |  | ok |
| 3V3 | 2.865 | 2.7..3.0 | ok |
| 1V1_CORE | 1.096 |  | ok |
| MIC_3V3_FILT | 2.864 |  | ok |
| 3V3_PWRGD | 0.017 | 0..0.2 | ok |
| MCU_RUN | 2.865 |  | ok |
| QSPI_CS_FLASH | 2.865 |  | ok |
| QSPI_SS_MCU | 2.865 |  | ok |
| F13_BTN_N | 2.865 |  | ok |
| F14_BTN_N | 2.865 |  | ok |
| AMP_SD_MODE | 0.000 |  | ok |
| USB_CC1 | 0.000 |  | ok |
| USB_CC2 | 0.000 |  | ok |
| SPKR_P | 0.000 |  | ok |
| SPKR_N | 0.000 |  | ok |

fuse 53.8 mA, LDO out 53.6 mA (6 mW), RP2040 core reg 39.9 mA, I(R14) -0 µA, I(R7) -0 µA, I(R9) -285 µA

### USB unplugged

| Net | V | expected | ok |
|---|---|---|---|
| USB_VBUS_RAW | 0.000 |  | ok |
| VBUS_5V | 0.000 | 0..0.01 | ok |
| 3V3 | 0.000 | 0..0.01 | ok |
| 1V1_CORE | 0.000 | 0..0.01 | ok |
| MIC_3V3_FILT | 0.000 |  | ok |
| 3V3_PWRGD | 0.000 | 0..0.01 | ok |
| MCU_RUN | 0.000 | 0..0.01 | ok |
| QSPI_CS_FLASH | 0.000 |  | ok |
| QSPI_SS_MCU | 0.000 |  | ok |
| F13_BTN_N | 0.000 |  | ok |
| F14_BTN_N | 0.000 |  | ok |
| AMP_SD_MODE | 0.000 |  | ok |
| USB_CC1 | 0.000 |  | ok |
| USB_CC2 | 0.000 |  | ok |
| SPKR_P | 0.000 |  | ok |
| SPKR_N | 0.000 |  | ok |

fuse 0.0 mA, LDO out 0.0 mA (0 mW), RP2040 core reg 0.0 mA, I(R14) 0 µA, I(R7) 0 µA, I(R9) 0 µA

## Model assumptions

- Sources/loads: USB 5 V with 0.1 Ω; fuse 0.5 Ω; ferrite 0.8 Ω; ESD array pass-through 10 mΩ; speaker 8 Ω.
- MCP1825: 3.3 V out, 100 mV dropout, PWRGD open-drain pulls low below 92 % of 3.3 V, enabled when SHDN > 1.5 V.
- RP2040: core regulator 1.1 V when VREG_VIN > 1.6 V; core 40 mA, IOVDD 5 mA, USB_VDD 5 mA, ADC 0.5 mA; QSPI_SS/SWD internal 56 kΩ pull-ups; GPIO drivers 30 Ω.
- Flash 3 mA, mic 0.7 mA, amp 0.1 mA off / 240 mA at 1 W into 8 Ω; MAX98357A SD_MODE assumed to have a 100 kΩ internal pull-down.
- Capacitors and the crystal are open at DC; they are checked by net membership, value and distance instead.
- Two-terminal resistances are measured with all ICs unpowered and switches open unless stated.

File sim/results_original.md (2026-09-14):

# Wiring simulation results

Board: Claude Handset #3cf75256, netlist from asbuilt_original.json

**131 checks passed, 6 failed, 6 warnings (placement, not wiring).**

## Netlist: as-built copper vs intended

| Check | Result | Detail |
|---|---|---|
| no orphan pads / shorts / split nets | FAIL | pad VIA: intended 3V3_PWRGD but sits on 3V3; pad VIA: intended 3V3_PWRGD but sits on 3V3; pad VIA: intended 3V3_PWRGD but sits on 3V3; pad VIA: intended 3V3_PWRGD but sits on 3V3; pad VIA: intended 3V3_PWRGD but sits on 3V3; pad VIA: intended 3V3_PWRGD but sits on 3V3; pad R9:P2 intended 3V3_PWRGD but sits on 3V3; pad U1:GPIO intended 3V3_PWRGD but sits on 3V3; pad U5:PWRG intended 3V3_PWRGD but sits on 3V3; island 3V3 carries several intended nets: {'3V3': 24, '3V3_PWRGD': 9}; intended net 3V3 is split into 2 islands; intended net GND is split into 5 islands |
| RP2040 pin numbering matches netlist labels | PASS | 56 pins identified from pad geometry |
| GPIO2 = I2S_BCLK (per project description) | PASS | GPIO2 is on I2S_BCLK |
| GPIO3 = I2S_LRCLK (per project description) | PASS | GPIO3 is on I2S_LRCLK |
| GPIO4 = I2S_DAC_DATA (per project description) | PASS | GPIO4 is on I2S_DAC_DATA |
| GPIO5 = PDM_DATA (per project description) | PASS | GPIO5 is on PDM_DATA |
| GPIO6 = PDM_CLK (per project description) | PASS | GPIO6 is on PDM_CLK |
| GPIO21 = AMP_SD_MODE (per project description) | PASS | GPIO21 is on AMP_SD_MODE |
| GPIO7 assignment | PASS | GPIO7 is on F13_BTN_N |
| GPIO8 assignment | PASS | GPIO8 is on F14_BTN_N |
| GPIO9 assignment | PASS | GPIO9 is on 3V3 |
| all RP2040 IOVDD pins on one net | FAIL | IOVDD pins: {'3V3#2', '3V3'} |
| all RP2040 DVDD pins on one net | PASS | DVDD pins: {'1V1_CORE'} |
| RP2040 exposed pad on GND | FAIL | EP is on GND#3 |
| TESTEN tied to GND | PASS | TESTEN on GND |
| no unpowered IC supply pins | PASS | U2/U3/MK1/U5 supply pins connected |

## Wiring paths (2-terminal resistance, ICs unpowered)

| Check | Result | Detail |
|---|---|---|
| USB D+ : J1.DP1 -> D1 -> R3 -> RP2040 USB_DP | PASS | measured 27 Ω, expected 27 Ω |
| USB D- : J1.DN1 -> D1 -> R4 -> RP2040 USB_DM | PASS | measured 27 Ω, expected 27 Ω |
| USB D+ both connector pins tied (DP1-DP2) | PASS | measured 0.0 mΩ, expected 0.0 mΩ |
| USB D- both connector pins tied (DN1-DN2) | PASS | measured 0.0 mΩ, expected 0.0 mΩ |
| CC1 pull-down to GND (R1) | PASS | measured 5.1e+03 Ω, expected 5.1e+03 Ω |
| CC2 pull-down to GND (R2) | PASS | measured 5.1e+03 Ω, expected 5.1e+03 Ω |
| VBUS: J1.VBUS -> F1 -> VBUS_5V (fuse) | PASS | measured 0.5 Ω, expected 0.5 Ω |
| VBUS_5V -> amp VDD | PASS | measured 0.0 mΩ, expected 0.0 mΩ |
| VBUS_5V -> LDO SHDN (always enabled) | PASS | measured 0.0 mΩ, expected 0.0 mΩ |
| 3V3 -> FB1 -> mic VDD | PASS | measured 0.8 Ω, expected 0.8 Ω |
| 3V3 -> flash VCC | PASS | measured 0.0 mΩ, expected 0.0 mΩ |
| 3V3 -> SWD header pin 1 | PASS | measured 0.0 mΩ, expected 0.0 mΩ |
| RP2040 VREG_VOUT -> DVDD (1V1 core) | PASS | measured 0.0 mΩ, expected 0.0 mΩ |
| XIN -> Y1 | PASS | measured 0.0 mΩ, expected 0.0 mΩ |
| XOUT -> R5 -> Y1 | PASS | measured 1e+03 Ω, expected 1e+03 Ω |
| QSPI_SS -> R6 -> flash CS | PASS | measured 1e+03 Ω, expected 1e+03 Ω |
| flash CS pull-up R7 to 3V3 | PASS | measured 1e+04 Ω, expected 1e+04 Ω |
| QSPI_SCLK -> flash CLK | PASS | measured 0.0 mΩ, expected 0.0 mΩ |
| QSPI_SD0 -> flash DI (IO0) | PASS | measured 0.0 mΩ, expected 0.0 mΩ |
| QSPI_SD1 -> flash DO (IO1) | PASS | measured 0.0 mΩ, expected 0.0 mΩ |
| QSPI_SD2 -> flash WP# (IO2) | PASS | measured 0.0 mΩ, expected 0.0 mΩ |
| QSPI_SD3 -> flash HOLD (IO3) | PASS | measured 0.0 mΩ, expected 0.0 mΩ |
| GPIO2 -> amp BCLK | PASS | measured 0.0 mΩ, expected 0.0 mΩ |
| GPIO3 -> amp LRCLK | PASS | measured 0.0 mΩ, expected 0.0 mΩ |
| GPIO4 -> amp DIN | PASS | measured 0.0 mΩ, expected 0.0 mΩ |
| GPIO21 -> amp SD_MODE | PASS | measured 0.0 mΩ, expected 0.0 mΩ |
| amp OUTP -> J3 pin 1 | PASS | measured 0.0 mΩ, expected 0.0 mΩ |
| amp OUTN -> J3 pin 2 | PASS | measured 0.0 mΩ, expected 0.0 mΩ |
| speaker terminals not grounded (J3.1 -> GND) | PASS | measured open (>1 MΩ), expected open |
| speaker terminals not grounded (J3.2 -> GND) | PASS | measured open (>1 MΩ), expected open |
| GPIO6 -> mic CLK | PASS | measured 0.0 mΩ, expected 0.0 mΩ |
| GPIO5 -> mic DATA | PASS | measured 0.0 mΩ, expected 0.0 mΩ |
| mic SELECT tied low | PASS | measured 0.0 mΩ, expected 0.0 mΩ |
| SWD header: SWDIO | PASS | measured 0.0 mΩ, expected 0.0 mΩ |
| SWD header: SWCLK | PASS | measured 0.0 mΩ, expected 0.0 mΩ |
| SWD header: RUN | PASS | measured 0.0 mΩ, expected 0.0 mΩ |
| SWD header: GND | PASS | measured 0.0 mΩ, expected 0.0 mΩ |
| RUN pull-up R8 to 3V3 | PASS | measured 1e+04 Ω, expected 1e+04 Ω |
| PWRGD pull-up R9 to 3V3 | FAIL | measured 0.0 mΩ, expected 1e+04 Ω |
| PWRGD -> GPIO9 | PASS | measured 0.0 mΩ, expected 0.0 mΩ |
| F13 pull-up R14 to 3V3 | PASS | measured 1e+04 Ω, expected 1e+04 Ω |
| F14 pull-up R15 to 3V3 | PASS | measured 1e+04 Ω, expected 1e+04 Ω |
| no DC path 3V3 -> GND with everything off | PASS | measured open (>1 MΩ), expected open |
| no DC path VBUS_5V -> GND with everything off | PASS | measured open (>1 MΩ), expected open |
| no DC path 1V1 -> GND with everything off | PASS | measured open (>1 MΩ), expected open |
| USB D+ isolated from D- | PASS | measured open (>1 MΩ), expected open |
| USB D+ isolated from GND | PASS | measured open (>1 MΩ), expected open |
| SW1 shorts F13_BTN_N to GND | PASS | closed: 50.0 mΩ; open: open (>1 MΩ) |
| SW2 shorts F14_BTN_N to GND | PASS | closed: 50.0 mΩ; open: open (>1 MΩ) |
| SW3 shorts MCU_RUN to GND | PASS | closed: 50.0 mΩ; open: open (>1 MΩ) |
| SW4 shorts QSPI_CS_FLASH to GND | PASS | closed: 50.0 mΩ; open: open (>1 MΩ) |

## Decoupling capacitors (net + distance to the pin they serve)

| Check | Result | Detail |
|---|---|---|
| RP2040 pin 1 IOVDD (3V3) | PASS | nearest cap C5 100 nF at 2.07 mm |
| RP2040 pin 10 IOVDD (3V3) | PASS | nearest cap C4 100 nF at 2.20 mm |
| RP2040 pin 22 IOVDD (3V3) | WARN | nearest cap C6 100 nF at 4.15 mm |
| RP2040 pin 33 IOVDD (3V3#2) | PASS | nearest cap C7 100 nF at 2.20 mm |
| RP2040 pin 42 IOVDD (3V3#2) | PASS | nearest cap C8 100 nF at 2.07 mm |
| RP2040 pin 49 IOVDD (3V3#2) | PASS | nearest cap C15 100 nF at 2.68 mm |
| RP2040 pin 48 USB_VDD (3V3#2) | PASS | nearest cap C15 100 nF at 3.00 mm |
| RP2040 pin 43 ADC_AVDD (3V3#2) | PASS | nearest cap C8 100 nF at 2.98 mm |
| RP2040 pin 44 VREG_VIN (3V3#2) | WARN | nearest cap C8 100 nF at 3.37 mm |
| RP2040 pin 23 DVDD (1V1_CORE) | WARN | nearest cap C11 100 nF at 11.05 mm |
| RP2040 pin 50 DVDD (1V1_CORE) | WARN | nearest cap C11 100 nF at 5.79 mm |
| RP2040 pin 45 VREG_VOUT (1V1_CORE) | WARN | nearest cap C11 100 nF at 7.66 mm |
| flash VCC (3V3) | PASS | nearest cap C17 100 nF at 1.49 mm |
| amp VDD (VBUS_5V) | WARN | nearest cap C25 10000 nF at 5.13 mm |
| mic VDD (filtered) (MIC_3V3_FILT) | PASS | nearest cap C28 100 nF at 1.65 mm |
| LDO input (VBUS_5V) | PASS | nearest cap C2 10000 nF at 2.50 mm |
| LDO output (3V3) | PASS | nearest cap C3 10000 nF at 2.34 mm |
| crystal load caps 27 pF on XIN and XOUT sides | PASS | C12 on {'GND', 'XOSC_XI'}, C18 on {'XOSC_XO', 'GND'} |
| RUN reset RC (R8 + C20) | PASS | C20 on {'MCU_RUN', 'GND'}; tau = 1.0 ms |

## DC scenarios

| Check | Result | Detail |
|---|---|---|
| USB plugged, idle: V(USB_VBUS_RAW) | PASS | 4.999 V (expected 4.95..5.0 V) |
| USB plugged, idle: V(VBUS_5V) | PASS | 4.995 V (expected 4.9..5.0 V) |
| USB plugged, idle: V(3V3) | PASS | 3.300 V (expected 3.25..3.35 V) |
| USB plugged, idle: V(1V1_CORE) | FAIL | 0.000 V (expected 1.05..1.15 V) |
| USB plugged, idle: V(MIC_3V3_FILT) | PASS | 3.299 V (expected 3.25..3.35 V) |
| USB plugged, idle: V(3V3_PWRGD) | FAIL | 0.000 V (expected 3.2..3.35 V) |
| USB plugged, idle: V(MCU_RUN) | PASS | 3.300 V (expected 3.2..3.35 V) |
| USB plugged, idle: V(QSPI_CS_FLASH) | PASS | 3.300 V (expected 3.2..3.35 V) |
| USB plugged, idle: V(QSPI_SS_MCU) | PASS | 3.300 V (expected 3.2..3.35 V) |
| USB plugged, idle: V(F13_BTN_N) | PASS | 3.300 V (expected 3.2..3.35 V) |
| USB plugged, idle: V(F14_BTN_N) | PASS | 3.300 V (expected 3.2..3.35 V) |
| USB plugged, idle: V(AMP_SD_MODE) | PASS | 0.000 V (expected 0..0.05 V) |
| USB plugged, idle: V(USB_CC1) | PASS | 0.000 V (expected 0..0.01 V) |
| USB plugged, idle: V(USB_CC2) | PASS | 0.000 V (expected 0..0.01 V) |
| USB plugged, idle: fuse current below 0.5 A hold | PASS | 9 mA through F1 |
| USB plugged, idle: LDO within 500 mA and dissipation sane | PASS | LDO out 8.7 mA, dissipation 15 mW |
| F13 button pressed: V(3V3) | PASS | 3.300 V (expected 3.25..3.35 V) |
| F13 button pressed: V(F13_BTN_N) | PASS | 0.000 V (expected 0..0.05 V) |
| F13 button pressed: V(F14_BTN_N) | PASS | 3.300 V (expected 3.2..3.35 V) |
| F13 button pressed: fuse current below 0.5 A hold | PASS | 9 mA through F1 |
| F13 button pressed: LDO within 500 mA and dissipation sane | PASS | LDO out 9.0 mA, dissipation 15 mW |
| F14 button pressed: V(3V3) | PASS | 3.300 V (expected 3.25..3.35 V) |
| F14 button pressed: V(F13_BTN_N) | PASS | 3.300 V (expected 3.2..3.35 V) |
| F14 button pressed: V(F14_BTN_N) | PASS | 0.000 V (expected 0..0.05 V) |
| F14 button pressed: fuse current below 0.5 A hold | PASS | 9 mA through F1 |
| F14 button pressed: LDO within 500 mA and dissipation sane | PASS | LDO out 9.0 mA, dissipation 15 mW |
| SW3 pressed (RUN low = reset): V(3V3) | PASS | 3.300 V (expected 3.25..3.35 V) |
| SW3 pressed (RUN low = reset): V(MCU_RUN) | PASS | 0.000 V (expected 0..0.05 V) |
| SW3 pressed (RUN low = reset): V(QSPI_CS_FLASH) | PASS | 3.299 V (expected 3.2..3.35 V) |
| SW3 pressed (RUN low = reset): fuse current below 0.5 A hold | PASS | 9 mA through F1 |
| SW3 pressed (RUN low = reset): LDO within 500 mA and dissipation sane | PASS | LDO out 9.0 mA, dissipation 15 mW |
| SW4 pressed (flash CS low = BOOTSEL): V(MCU_RUN) | PASS | 3.300 V (expected 3.2..3.35 V) |
| SW4 pressed (flash CS low = BOOTSEL): V(QSPI_CS_FLASH) | PASS | 0.000 V (expected 0..0.05 V) |
| SW4 pressed (flash CS low = BOOTSEL): V(QSPI_SS_MCU) | PASS | 0.058 V (expected 0..0.4 V) |
| SW4 pressed (flash CS low = BOOTSEL): fuse current below 0.5 A hold | PASS | 9 mA through F1 |
| SW4 pressed (flash CS low = BOOTSEL): LDO within 500 mA and dissipation sane | PASS | LDO out 9.1 mA, dissipation 15 mW |
| Debugger holds RUN low via J4: V(3V3) | PASS | 3.300 V (expected 3.25..3.35 V) |
| Debugger holds RUN low via J4: V(MCU_RUN) | PASS | 0.000 V (expected 0..0.05 V) |
| Debugger holds RUN low via J4: fuse current below 0.5 A hold | PASS | 9 mA through F1 |
| Debugger holds RUN low via J4: LDO within 500 mA and dissipation sane | PASS | LDO out 9.0 mA, dissipation 15 mW |
| Amp enabled, 1 W playing (GPIO21 high): V(VBUS_5V) | PASS | 4.855 V (expected 4.7..5.0 V) |
| Amp enabled, 1 W playing (GPIO21 high): V(3V3) | PASS | 3.300 V (expected 3.25..3.35 V) |
| Amp enabled, 1 W playing (GPIO21 high): V(AMP_SD_MODE) | PASS | 3.299 V (expected 3.0..3.35 V) |
| Amp enabled, 1 W playing (GPIO21 high): fuse current below 0.5 A hold | PASS | 242 mA through F1 |
| Amp enabled, 1 W playing (GPIO21 high): LDO within 500 mA and dissipation sane | PASS | LDO out 8.7 mA, dissipation 14 mW |
| Amp disabled (GPIO21 low): V(AMP_SD_MODE) | PASS | 0.000 V (expected 0..0.05 V) |
| Amp disabled (GPIO21 low): fuse current below 0.5 A hold | PASS | 9 mA through F1 |
| Amp disabled (GPIO21 low): LDO within 500 mA and dissipation sane | PASS | LDO out 8.7 mA, dissipation 15 mW |
| USB brown-out to 3.0 V: V(3V3) | PASS | 2.864 V (expected 2.7..3.0 V) |
| USB brown-out to 3.0 V: V(3V3_PWRGD) | PASS | 0.000 V (expected 0..0.2 V) |
| USB brown-out to 3.0 V: fuse current below 0.5 A hold | PASS | 55 mA through F1 |
| USB brown-out to 3.0 V: LDO within 500 mA and dissipation sane | PASS | LDO out 55.3 mA, dissipation 6 mW |
| USB unplugged: V(VBUS_5V) | PASS | 0.000 V (expected 0..0.01 V) |
| USB unplugged: V(3V3) | PASS | 0.000 V (expected 0..0.01 V) |
| USB unplugged: V(1V1_CORE) | PASS | 0.000 V (expected 0..0.01 V) |
| USB unplugged: V(3V3_PWRGD) | PASS | 0.000 V (expected 0..0.01 V) |
| USB unplugged: V(MCU_RUN) | PASS | 0.000 V (expected 0..0.01 V) |

## Scenario operating points

### USB plugged, idle

| Net | V | expected | ok |
|---|---|---|---|
| USB_VBUS_RAW | 4.999 | 4.95..5.0 | ok |
| VBUS_5V | 4.995 | 4.9..5.0 | ok |
| 3V3 | 3.300 | 3.25..3.35 | ok |
| 1V1_CORE | 0.000 | 1.05..1.15 | FAIL |
| MIC_3V3_FILT | 3.299 | 3.25..3.35 | ok |
| 3V3_PWRGD | 0.000 | 3.2..3.35 | FAIL |
| MCU_RUN | 3.300 | 3.2..3.35 | ok |
| QSPI_CS_FLASH | 3.300 | 3.2..3.35 | ok |
| QSPI_SS_MCU | 3.300 | 3.2..3.35 | ok |
| F13_BTN_N | 3.300 | 3.2..3.35 | ok |
| F14_BTN_N | 3.300 | 3.2..3.35 | ok |
| AMP_SD_MODE | 0.000 | 0..0.05 | ok |
| USB_CC1 | 0.000 | 0..0.01 | ok |
| USB_CC2 | 0.000 | 0..0.01 | ok |
| SPKR_P | 0.000 |  | ok |
| SPKR_N | 0.000 |  | ok |

fuse 8.9 mA, LDO out 8.7 mA (15 mW), RP2040 core reg 0.0 mA, I(R14) -0 µA, I(R7) -0 µA, I(R9) 0 µA

### F13 button pressed

| Net | V | expected | ok |
|---|---|---|---|
| USB_VBUS_RAW | 4.999 |  | ok |
| VBUS_5V | 4.994 |  | ok |
| 3V3 | 3.300 | 3.25..3.35 | ok |
| 1V1_CORE | 0.000 |  | ok |
| MIC_3V3_FILT | 3.299 |  | ok |
| 3V3_PWRGD | 0.000 |  | ok |
| MCU_RUN | 3.300 |  | ok |
| QSPI_CS_FLASH | 3.299 |  | ok |
| QSPI_SS_MCU | 3.299 |  | ok |
| F13_BTN_N | 0.000 | 0..0.05 | ok |
| F14_BTN_N | 3.300 | 3.2..3.35 | ok |
| AMP_SD_MODE | 0.000 |  | ok |
| USB_CC1 | 0.000 |  | ok |
| USB_CC2 | 0.000 |  | ok |
| SPKR_P | 0.000 |  | ok |
| SPKR_N | 0.000 |  | ok |

fuse 9.2 mA, LDO out 9.0 mA (15 mW), RP2040 core reg 0.0 mA, I(R14) -330 µA, I(R7) -0 µA, I(R9) 0 µA

### F14 button pressed

| Net | V | expected | ok |
|---|---|---|---|
| USB_VBUS_RAW | 4.999 |  | ok |
| VBUS_5V | 4.994 |  | ok |
| 3V3 | 3.300 | 3.25..3.35 | ok |
| 1V1_CORE | 0.000 |  | ok |
| MIC_3V3_FILT | 3.299 |  | ok |
| 3V3_PWRGD | 0.000 |  | ok |
| MCU_RUN | 3.300 |  | ok |
| QSPI_CS_FLASH | 3.299 |  | ok |
| QSPI_SS_MCU | 3.299 |  | ok |
| F13_BTN_N | 3.300 | 3.2..3.35 | ok |
| F14_BTN_N | 0.000 | 0..0.05 | ok |
| AMP_SD_MODE | 0.000 |  | ok |
| USB_CC1 | 0.000 |  | ok |
| USB_CC2 | 0.000 |  | ok |
| SPKR_P | 0.000 |  | ok |
| SPKR_N | 0.000 |  | ok |

fuse 9.2 mA, LDO out 9.0 mA (15 mW), RP2040 core reg 0.0 mA, I(R14) -0 µA, I(R7) -0 µA, I(R9) 0 µA

### SW3 pressed (RUN low = reset)

| Net | V | expected | ok |
|---|---|---|---|
| USB_VBUS_RAW | 4.999 |  | ok |
| VBUS_5V | 4.994 |  | ok |
| 3V3 | 3.300 | 3.25..3.35 | ok |
| 1V1_CORE | 0.000 |  | ok |
| MIC_3V3_FILT | 3.299 |  | ok |
| 3V3_PWRGD | 0.000 |  | ok |
| MCU_RUN | 0.000 | 0..0.05 | ok |
| QSPI_CS_FLASH | 3.299 | 3.2..3.35 | ok |
| QSPI_SS_MCU | 3.299 |  | ok |
| F13_BTN_N | 3.300 |  | ok |
| F14_BTN_N | 3.300 |  | ok |
| AMP_SD_MODE | 0.000 |  | ok |
| USB_CC1 | 0.000 |  | ok |
| USB_CC2 | 0.000 |  | ok |
| SPKR_P | 0.000 |  | ok |
| SPKR_N | 0.000 |  | ok |

fuse 9.2 mA, LDO out 9.0 mA (15 mW), RP2040 core reg 0.0 mA, I(R14) -0 µA, I(R7) -0 µA, I(R9) 0 µA

### SW4 pressed (flash CS low = BOOTSEL)

| Net | V | expected | ok |
|---|---|---|---|
| USB_VBUS_RAW | 4.999 |  | ok |
| VBUS_5V | 4.994 |  | ok |
| 3V3 | 3.300 |  | ok |
| 1V1_CORE | 0.000 |  | ok |
| MIC_3V3_FILT | 3.299 |  | ok |
| 3V3_PWRGD | 0.000 |  | ok |
| MCU_RUN | 3.300 | 3.2..3.35 | ok |
| QSPI_CS_FLASH | 0.000 | 0..0.05 | ok |
| QSPI_SS_MCU | 0.058 | 0..0.4 | ok |
| F13_BTN_N | 3.300 |  | ok |
| F14_BTN_N | 3.300 |  | ok |
| AMP_SD_MODE | 0.000 |  | ok |
| USB_CC1 | 0.000 |  | ok |
| USB_CC2 | 0.000 |  | ok |
| SPKR_P | 0.000 |  | ok |
| SPKR_N | 0.000 |  | ok |

fuse 9.3 mA, LDO out 9.1 mA (15 mW), RP2040 core reg 0.0 mA, I(R14) -0 µA, I(R7) -330 µA, I(R9) 0 µA

### Debugger holds RUN low via J4

| Net | V | expected | ok |
|---|---|---|---|
| USB_VBUS_RAW | 4.999 |  | ok |
| VBUS_5V | 4.994 |  | ok |
| 3V3 | 3.300 | 3.25..3.35 | ok |
| 1V1_CORE | 0.000 |  | ok |
| MIC_3V3_FILT | 3.299 |  | ok |
| 3V3_PWRGD | 0.000 |  | ok |
| MCU_RUN | 0.000 | 0..0.05 | ok |
| QSPI_CS_FLASH | 3.299 |  | ok |
| QSPI_SS_MCU | 3.299 |  | ok |
| F13_BTN_N | 3.300 |  | ok |
| F14_BTN_N | 3.300 |  | ok |
| AMP_SD_MODE | 0.000 |  | ok |
| USB_CC1 | 0.000 |  | ok |
| USB_CC2 | 0.000 |  | ok |
| SPKR_P | 0.000 |  | ok |
| SPKR_N | 0.000 |  | ok |

fuse 9.2 mA, LDO out 9.0 mA (15 mW), RP2040 core reg 0.0 mA, I(R14) -0 µA, I(R7) -0 µA, I(R9) 0 µA

### Amp enabled, 1 W playing (GPIO21 high)

| Net | V | expected | ok |
|---|---|---|---|
| USB_VBUS_RAW | 4.976 |  | ok |
| VBUS_5V | 4.855 | 4.7..5.0 | ok |
| 3V3 | 3.300 | 3.25..3.35 | ok |
| 1V1_CORE | 0.000 |  | ok |
| MIC_3V3_FILT | 3.299 |  | ok |
| 3V3_PWRGD | 0.000 |  | ok |
| MCU_RUN | 3.300 |  | ok |
| QSPI_CS_FLASH | 3.300 |  | ok |
| QSPI_SS_MCU | 3.300 |  | ok |
| F13_BTN_N | 3.300 |  | ok |
| F14_BTN_N | 3.300 |  | ok |
| AMP_SD_MODE | 3.299 | 3.0..3.35 | ok |
| USB_CC1 | 0.000 |  | ok |
| USB_CC2 | 0.000 |  | ok |
| SPKR_P | 0.000 |  | ok |
| SPKR_N | 0.000 |  | ok |

fuse 241.9 mA, LDO out 8.7 mA (14 mW), RP2040 core reg 0.0 mA, I(R14) -0 µA, I(R7) -0 µA, I(R9) 0 µA

### Amp disabled (GPIO21 low)

| Net | V | expected | ok |
|---|---|---|---|
| USB_VBUS_RAW | 4.999 |  | ok |
| VBUS_5V | 4.995 |  | ok |
| 3V3 | 3.300 |  | ok |
| 1V1_CORE | 0.000 |  | ok |
| MIC_3V3_FILT | 3.299 |  | ok |
| 3V3_PWRGD | 0.000 |  | ok |
| MCU_RUN | 3.300 |  | ok |
| QSPI_CS_FLASH | 3.300 |  | ok |
| QSPI_SS_MCU | 3.300 |  | ok |
| F13_BTN_N | 3.300 |  | ok |
| F14_BTN_N | 3.300 |  | ok |
| AMP_SD_MODE | 0.000 | 0..0.05 | ok |
| USB_CC1 | 0.000 |  | ok |
| USB_CC2 | 0.000 |  | ok |
| SPKR_P | 0.000 |  | ok |
| SPKR_N | 0.000 |  | ok |

fuse 8.9 mA, LDO out 8.7 mA (15 mW), RP2040 core reg 0.0 mA, I(R14) -0 µA, I(R7) -0 µA, I(R9) 0 µA

### USB brown-out to 3.0 V

| Net | V | expected | ok |
|---|---|---|---|
| USB_VBUS_RAW | 2.994 |  | ok |
| VBUS_5V | 2.967 |  | ok |
| 3V3 | 2.864 | 2.7..3.0 | ok |
| 1V1_CORE | 0.000 |  | ok |
| MIC_3V3_FILT | 2.863 |  | ok |
| 3V3_PWRGD | 0.000 | 0..0.2 | ok |
| MCU_RUN | 2.864 |  | ok |
| QSPI_CS_FLASH | 2.864 |  | ok |
| QSPI_SS_MCU | 2.864 |  | ok |
| F13_BTN_N | 2.864 |  | ok |
| F14_BTN_N | 2.864 |  | ok |
| AMP_SD_MODE | 0.000 |  | ok |
| USB_CC1 | 0.000 |  | ok |
| USB_CC2 | 0.000 |  | ok |
| SPKR_P | 0.000 |  | ok |
| SPKR_N | 0.000 |  | ok |

fuse 55.5 mA, LDO out 55.3 mA (6 mW), RP2040 core reg 0.0 mA, I(R14) -0 µA, I(R7) -0 µA, I(R9) 0 µA

### USB unplugged

| Net | V | expected | ok |
|---|---|---|---|
| USB_VBUS_RAW | 0.000 |  | ok |
| VBUS_5V | 0.000 | 0..0.01 | ok |
| 3V3 | 0.000 | 0..0.01 | ok |
| 1V1_CORE | 0.000 | 0..0.01 | ok |
| MIC_3V3_FILT | 0.000 |  | ok |
| 3V3_PWRGD | 0.000 | 0..0.01 | ok |
| MCU_RUN | 0.000 | 0..0.01 | ok |
| QSPI_CS_FLASH | 0.000 |  | ok |
| QSPI_SS_MCU | 0.000 |  | ok |
| F13_BTN_N | 0.000 |  | ok |
| F14_BTN_N | 0.000 |  | ok |
| AMP_SD_MODE | 0.000 |  | ok |
| USB_CC1 | 0.000 |  | ok |
| USB_CC2 | 0.000 |  | ok |
| SPKR_P | 0.000 |  | ok |
| SPKR_N | 0.000 |  | ok |

fuse 0.0 mA, LDO out 0.0 mA (0 mW), RP2040 core reg 0.0 mA, I(R14) 0 µA, I(R7) 0 µA, I(R9) 0 µA

## Model assumptions

- Sources/loads: USB 5 V with 0.1 Ω; fuse 0.5 Ω; ferrite 0.8 Ω; ESD array pass-through 10 mΩ; speaker 8 Ω.
- MCP1825: 3.3 V out, 100 mV dropout, PWRGD open-drain pulls low below 92 % of 3.3 V, enabled when SHDN > 1.5 V.
- RP2040: core regulator 1.1 V when VREG_VIN > 1.6 V; core 40 mA, IOVDD 5 mA, USB_VDD 5 mA, ADC 0.5 mA; QSPI_SS/SWD internal 56 kΩ pull-ups; GPIO drivers 30 Ω.
- Flash 3 mA, mic 0.7 mA, amp 0.1 mA off / 240 mA at 1 W into 8 Ω; MAX98357A SD_MODE assumed to have a 100 kΩ internal pull-down.
- Capacitors and the crystal are open at DC; they are checked by net membership, value and distance instead.
- Two-terminal resistances are measured with all ICs unpowered and switches open unless stated.

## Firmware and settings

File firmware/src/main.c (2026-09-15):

/*
 * Claude Handset firmware.
 *
 * USB composite device: UAC2 speaker + microphone, boot-protocol HID keyboard
 * (F13 / F14 on the two side buttons), and a picotool reset interface.
 * Everything runs from a single cooperative main loop; audio moves through
 * PIO and DMA in the background.
 */

#include "pico/stdlib.h"
#include "hardware/watchdog.h"
#include "tusb.h"

#include "usb_audio.h"
#include "buttons.h"
#include "diag.h"

#if HANDSET_HAS_PWRGD
static void pwrgd_init(void) {
  gpio_init(HANDSET_PIN_PWRGD);
  gpio_set_dir(HANDSET_PIN_PWRGD, GPIO_IN);
  gpio_set_pulls(HANDSET_PIN_PWRGD, false, false);   // 10 k pull-up on the board
}

static void pwrgd_task(void) {
  static uint32_t next_us;
  uint32_t now = time_us_32();
  if ((int32_t) (now - next_us) < 0) return;
  next_us = now + 1000;
  usb_audio_set_power_good(gpio_get(HANDSET_PIN_PWRGD));
}
#else
static void pwrgd_init(void) {}
static void pwrgd_task(void) {}
#endif

int main(void) {
  // Watchdog + crash breadcrumbs; see diag.h for the reboot policy.
  diag_boot();

  DIAG_CRUMB(1);
  pwrgd_init();
  buttons_init();

  // USB first so the host sees the device as early as possible.
  tusb_rhport_init_t dev_init = {
    .role = TUSB_ROLE_DEVICE,
    .speed = TUSB_SPEED_AUTO
  };
  DIAG_CRUMB(2);
  tusb_init(0, &dev_init);
  watchdog_update();

  DIAG_CRUMB(3);
  usb_audio_init();

  while (true) {
    DIAG_LOOP();
    DIAG_CRUMB(10); tud_task();
    DIAG_CRUMB(11); usb_audio_speaker_task();
    DIAG_CRUMB(12); usb_audio_mic_task();
    DIAG_CRUMB(13); buttons_task();
    DIAG_CRUMB(14); pwrgd_task();
    DIAG_CRUMB(15); diag_task();
    watchdog_update();
  }
}

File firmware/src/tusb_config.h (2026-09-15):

/*
 * TinyUSB configuration for the Claude Handset.
 *
 * One USB 2.0 full-speed composite device:
 *   - UAC2 audio function: 48 kHz / 16-bit stereo speaker (asynchronous OUT
 *     endpoint with explicit feedback) and 48 kHz / 16-bit mono microphone.
 *   - Boot-protocol HID keyboard for the two side buttons (F13 / F14).
 *   - Raspberry Pi "reset" vendor interface so picotool can reboot the board
 *     into BOOTSEL without touching the buttons.
 */

#ifndef TUSB_CONFIG_H_
#define TUSB_CONFIG_H_

#ifdef __cplusplus
extern "C" {
#endif

#include "usb_descriptors.h"

//--------------------------------------------------------------------
// Common
//--------------------------------------------------------------------

#ifndef CFG_TUSB_MCU
#define CFG_TUSB_MCU                OPT_MCU_RP2040
#endif

#ifndef CFG_TUSB_OS
#define CFG_TUSB_OS                 OPT_OS_PICO
#endif

#ifndef CFG_TUSB_DEBUG
#define CFG_TUSB_DEBUG              0
#endif

#define CFG_TUD_ENABLED             1
#define CFG_TUD_MAX_SPEED           OPT_MODE_FULL_SPEED

#ifndef CFG_TUSB_MEM_SECTION
#define CFG_TUSB_MEM_SECTION
#endif

#ifndef CFG_TUSB_MEM_ALIGN
#define CFG_TUSB_MEM_ALIGN          __attribute__ ((aligned(4)))
#endif

//--------------------------------------------------------------------
// Device
//--------------------------------------------------------------------

#define CFG_TUD_ENDPOINT0_SIZE      64

#define CFG_TUD_AUDIO               1
#define CFG_TUD_HID                 1
#define CFG_TUD_CDC                 0
#define CFG_TUD_MSC                 0
#define CFG_TUD_MIDI                0
#define CFG_TUD_VENDOR              0

//--------------------------------------------------------------------
// Audio (UAC2)
//--------------------------------------------------------------------

#define HANDSET_SAMPLE_RATE                             48000
#define HANDSET_SPK_CHANNELS                            2
#define HANDSET_MIC_CHANNELS                            1
#define HANDSET_BYTES_PER_SAMPLE                        2
#define HANDSET_BITS_PER_SAMPLE                         16

#define CFG_TUD_AUDIO_FUNC_1_DESC_LEN                   HANDSET_AUDIO_DESC_LEN
#define CFG_TUD_AUDIO_FUNC_1_N_AS_INT                   2   // speaker + microphone streaming interfaces
#define CFG_TUD_AUDIO_FUNC_1_CTRL_BUF_SZ                64

#define CFG_TUD_AUDIO_ENABLE_INTERRUPT_EP               0
#define CFG_TUD_AUDIO_ENABLE_FEEDBACK_EP                1
#define CFG_TUD_AUDIO_ENABLE_FEEDBACK_FORMAT_CORRECTION 1   // full speed: send 10.14 in 3 bytes per the USB spec
#define CFG_TUD_AUDIO_EP_IN_FLOW_CONTROL                1

// Microphone: EP IN
#define CFG_TUD_AUDIO_ENABLE_EP_IN                      1
#define CFG_TUD_AUDIO_FUNC_1_EP_IN_SZ_MAX               TUD_AUDIO_EP_SIZE(HANDSET_SAMPLE_RATE, HANDSET_BYTES_PER_SAMPLE, HANDSET_MIC_CHANNELS)
#define CFG_TUD_AUDIO_FUNC_1_EP_IN_SW_BUF_SZ            (8 * CFG_TUD_AUDIO_FUNC_1_EP_IN_SZ_MAX)

// Speaker: EP OUT. The FIFO-count feedback method regulates this buffer to
// half full, so 8 packets gives ~4 ms of buffering against USB jitter.
#define CFG_TUD_AUDIO_ENABLE_EP_OUT                     1
#define CFG_TUD_AUDIO_FUNC_1_EP_OUT_SZ_MAX              TUD_AUDIO_EP_SIZE(HANDSET_SAMPLE_RATE, HANDSET_BYTES_PER_SAMPLE, HANDSET_SPK_CHANNELS)
#define CFG_TUD_AUDIO_FUNC_1_EP_OUT_SW_BUF_SZ           (8 * CFG_TUD_AUDIO_FUNC_1_EP_OUT_SZ_MAX)

//--------------------------------------------------------------------
// HID
//--------------------------------------------------------------------

#define CFG_TUD_HID_EP_BUFSIZE      8

#ifdef __cplusplus
}
#endif

#endif /* TUSB_CONFIG_H_ */

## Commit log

2026-09-14 Claude Handset hardware: patched Gerbers, verification, JLCPCB order pack, STLs
    Hand-patched Flux export #3cf75256 with the DRC fixes, netlist simulator,
    JLCPCB order files and engineer-query notes, enclosure STLs, and a CLAUDE.md
    handoff for firmware work.
    Claude-Session: https://claude.ai/code/session_01ETwhqxG6asExYH5ySCuA9J
    [claude-handset-BOM-JLCPCB.csv, claude-handset-assembly.stl, claude-handset-board.stl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]
2026-09-15 Add RP2040 firmware: UAC2 speaker + PDM mic, HID keyboard, picotool reset interface
    pico-sdk 2.3.1 + TinyUSB 0.18. Composite USB device with 48 kHz stereo speaker
    out (I2S to the MAX98357A via PIO/DMA, async with feedback endpoint), 48 kHz mono
    mic in (PDM via PIO/DMA, sinc^4 + half-band decimation), boot-protocol keyboard
    on the side buttons (F17/F18; macOS binds F14/F15 to display brightness), and the
    Raspberry Pi vendor reset interface so picotool can reflash a running board.
    Includes a watchdog safe mode that reports crash breadcrumbs in the USB serial
    string, a workaround for TinyUSB's RP2040 ISO endpoint close bug, build/flash
    scripts, a browser key tester, and a README with the thing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
    [buttons.c, claude_handset.h, claude_handset_kb2040.h]
2026-09-15 Fix speaker: 10.14 feedback format; add live status request and host tool
    macOS accepted 4-byte 16.16 rate feedback for ~64 ms then stopped sending
    audio packets while leaving the interface streaming. Enabling TinyUSB's
    feedback format correction (3-byte 10.14 on full speed) fixes it; verified
    audible on the first board with a speaker on J3.
    Also adds a class-type status request on the reset interface that returns
    stream state, amp/power-good pins, FIFO levels, frame counters and PIO/DMA
    positions, plus tools/handset-status.c (libusb) to read it.
    Claude-Session: https://claude.ai/code/session_01SwiKoKssD8YopNkMcs3p3b
    [tusb_config.h]
